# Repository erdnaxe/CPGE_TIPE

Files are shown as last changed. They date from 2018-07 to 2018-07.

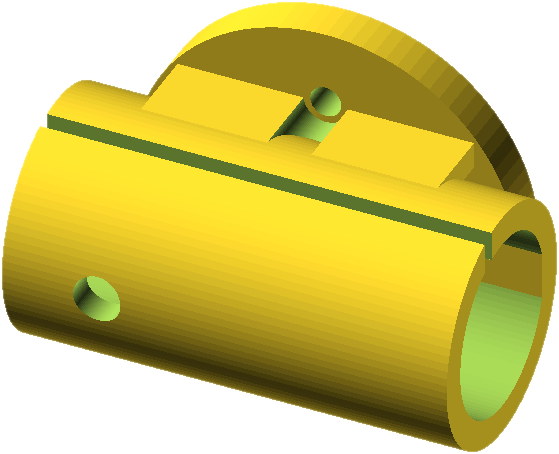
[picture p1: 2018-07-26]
listing_cao/cao/attache-tige_servo.png

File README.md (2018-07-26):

# Mon TIPE de CPGE PSI

Le sujet de mon TIPE est sur la création d'un stabilisateur motorisé à un axe.
Le but est de comprendre et réaliser un système similaire à
[l'OSMO de DJI](https://www.dji.com/fr/osmo).

## Licence

Tout ce TIPE est sous
[licence Creative Commons Attribution-ShareAlike 4.0 International](LICENCE.md).

À noter que SCEI sanctionne sévèrement la copie.

Pour le code, la plus grosse partie est sous
[licence GNU Lesser General Public](https://www.gnu.org/licenses/lgpl-3.0.en.html).

La police de caractère **TeX Gyre Pagella** est sous licence
[GUST Font Source Li­cense (GFSL)](https://ctan.org/license/gfsl).

Si vous avez des questions vous pouvez ouvrir un rapport de bug sur ce projet.

## Contenu

Vous trouverez dans les sous-dossiers :

* [Le listing du code](listing_code) et [le listing de la CAO](listing_cao)
  que j'ai apporté le jour de l'oral.

* [Le code pour traiter l'acquisition de l'expérience du pendule](experience_pendule)

* [La librairie pour contrôler le moteur sans-balais du banc d'essais](https://github.com/erdnaxe/Arduino_BrushlessServo)

* [Le code du banc d'essais sur l'ATMEGA328](tipe-banc_essais)

* [Le code qui permet d'effectuer un échelon sur l'ESP8266](tipe-echelon)

* [Le code qui permet la stabilisation sur l'ESP8266](tipe-stabilisateur)

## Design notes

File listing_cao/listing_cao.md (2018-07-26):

---
lang: fr-FR
papersize: a4
geometry: margin=1.8cm
numbersections: yes
title: Stabilisateur électronique -- CAO
author: Alexandre IOOSS
toc: yes
---

\newpage

\lstset{
  language=C++,
  morekeywords={difference, translate, cube, rotate, cylinder, use}
}

# Conception du stabilisateur

## Impression 3D du boitier accueillant l'électronique

\begin{center}
\vspace{20pt}
\includegraphics[width=0.7\textwidth]{cao/boitier.png}
\vspace{20pt}
\end{center}

## Impression 3D de l'attache de la tige au servomoteur

\begin{center}
\vspace{20pt}
\includegraphics[width=0.3\textwidth]{cao/attache-tige_servo.png}
\vspace{20pt}
\end{center}

Code **OpenSCAD** :

\lstinputlisting{cao/attache-tige_servo.scad}

\newpage

# Conception du banc d'essais

\begin{center}
\vspace{20pt}
\includegraphics[width=\textwidth]{cao/banc_vide.pdf}
\end{center}

\newpage

## Découpe laser des planches pour faire la structure

Échelle 30%. Planche de 6mm *Medium* découpée au laser dans le laboratoire de
fabrication *SqyLab*. Le tout est monté sur une planche de largeur 202mm et de
hauteur 22mm.

\begin{center}
\vspace{20pt}
\includegraphics[scale=0.3]{cao/banc_back.eps}

\includegraphics[scale=0.3]{cao/banc_left.eps}

\includegraphics[scale=0.3]{cao/banc_right.eps}
\end{center}

\newpage

## Impression 3D de l'attache du potentiomètre au banc d'essais

\begin{center}
\vspace{20pt}
\includegraphics[width=0.5\textwidth]{cao/attache_potentiometre.png}
\vspace{20pt}
\end{center}

Code **OpenSCAD** :

\lstinputlisting{cao/attache_potentiometre.scad}

\newpage

## Impression 3D de l'engrenage entre le moteur et le potentiomètre

\begin{center}
\vspace{20pt}
\includegraphics[width=0.3\textwidth]{cao/pignon_moteur.png}
\hspace{10pt}
\includegraphics[width=0.3\textwidth]{cao/pignon_potentiometre.png}
\vspace{20pt}
\end{center}

Code **OpenSCAD** du pignon du moteur :

\lstinputlisting{cao/pignon_moteur.scad}

Code **OpenSCAD** du pignon du potentiomètre :

\lstinputlisting{cao/pignon_potentiometre.scad}

\newpage

# Modèle pour trouver une approximation de l'inertie de l'appareil photo

Masse : 228 grammes

\begin{center}
\vspace{20pt}
\includegraphics[width=0.8\textwidth]{cao/modele_app_photo.pdf}
\vspace{20pt}
\end{center}

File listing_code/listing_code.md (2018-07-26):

---
lang: fr-FR
papersize: a4
geometry: margin=1.8cm
numbersections: yes
title: Stabilisateur électronique -- Listing
author: Alexandre IOOSS
toc: yes
---

\newpage

# Code utilisant le Framework Arduino (pour ATMEGA328p et ESP8266)

\lstset{
  language=C++,
  morekeywords={SimpleTimer, Servo, WebSocketsServer, IPAddress, WiFi, uint32_t, uint8_t, WStype_t, size_t, String}
}

## Bibliothèque pour asservir en position un moteur Brushless

Bibliothèque `BrushlessServo` maintenant publiée dans les contributions de l'éditeur Arduino.

### BrushlessServo.h

\lstinputlisting{brushlessservo/BrushlessServo.h}

### BrushlessServo.cpp

\lstinputlisting{brushlessservo/BrushlessServo.cpp}

### SinArray.h

\lstinputlisting{brushlessservo/SinArray.h}

### SinArray.cpp

\lstinputlisting{brushlessservo/SinArray.cpp}

\newpage

## Bibliothèque pour utiliser l'algorithme constructeur de la centrale inertielle

Programme basé sur l'example du projet *The I2C Device Library*.

### centrale_inertielle.h

\lstinputlisting{../tipe-banc_essais/src/centrale_inertielle.h}

### centrale_inertielle.cpp

\lstinputlisting{../tipe-banc_essais/src/centrale_inertielle.cpp}

\newpage

## Programme pour envoyer des commandes en rampe au servomoteur (ESP8266)

### main.cpp

\lstinputlisting{../tipe-echelon/src/main.cpp}

\newpage

## Programme embarqué sur le stabilisateur finalisé (ESP8266)

### main.cpp

\lstinputlisting{../tipe-stabilisateur/src/main.cpp}

\newpage

## Programme embarqué sur le banc d'essais (ATMega328p)

### main.cpp

\lstinputlisting{../tipe-banc_essais/src/main.cpp}

\newpage

## Bibliothèques externes

### WebSockets (Arduino Framework)

Utilisée sur le stabilisateur pour héberger un serveur au standard WebSocket.

Sous licence GNU LGPL 2.1+.

### SimpleTimer (Arduino Framework)

Utilisée sur le stabilisateur pour obtenir un semblant de multitâche.

Sous licence GNU LGPL 2.1+.

### PID (Brett Beauregard, Arduino Framework)

Utilisée sur le stabilisateur pour l'asservissement.

Développée par *Brett Beauregard* sous licence MIT.

### I2Cdevlib-MPU6050 (The I2C Device Library)

Utilisée pour envoyer l'algorithme constructeur (de MotionApps) sur le Digital
Motion Unit de la centrale inertielle.

Dérivée par le projet *The I2C Device Library* de la librarie de *MotionApps*
sous licence MIT.

\cleardoublepage

# Code Python

\lstset{
  language=Python,
  morekeywords={}
}

## Script pour tester le stabilisateur et configurer les coefficients du correcteur à la volée

### test_stabilisateur.py

\lstinputlisting{../tipe-stabilisateur/python/test_stabilisateur.py}

## Script pour commander le banc d'essais

### ComBanc.py : définit un objet représentant le banc d'essais

\lstinputlisting{../tipe-banc_essais/python/ComBanc.py}

\newpage

### Bode.py : définit un objet représentant un diagramme de Bode

\lstinputlisting{../tipe-banc_essais/python/Bode.py}

\newpage

### BodeTF.py : extension de l'objet Bode pour tracer une fonction de transfert

\lstinputlisting{../tipe-banc_essais/python/BodeTF.py}

\newpage

### test_banc.py : exemple de code pour une commande du banc

\lstinputlisting{../tipe-banc_essais/python/test_banc.py}

\newpage

### bode_centrale_inertielle.py : Création du Bode expérimental de la centrale inertielle

\lstinputlisting{../tipe-banc_essais/python/bode_centrale_inertielle.py}

\newpage

## Script pour le traitement du signal du pendule pesant

### pendule.py

\lstinputlisting{../experience_pendule/pendule.py}

\cleardoublepage

# Code MATLAB pour acquérir les rampes envoyées au servomoteur

\lstset{
  language=MatLab,
  morekeywords={classdef, methods, properties}
}

## Fonctions

### reel_faireAcquisition.m : acquisition d'une rampe sur le servomoteur

\lstinputlisting{../matlab/reel_faireAcquisition.m}

### reel_faireRegression.m : régression affine entre l'entrée et la sortie

\lstinputlisting{../matlab/reel_faireRegression.m}

### reel_rognerRampe.m : rogne le signal de 5s au début et à la fin

\lstinputlisting{../matlab/reel_rognerRampe.m}

### reel_traceCourbe.m : trace l'entrée et la sortie du servomoteur

\lstinputlisting{../matlab/reel_traceCourbe.m}

### reel_traceRegression.m : trace la sortie en fonction de l'entrée du servomoteur (avec superposition de la régression)

\lstinputlisting{../matlab/reel_traceRegression.m}

### reel_SystemeReel.m : définit un objet représentant la communication avec le système réel

\lstinputlisting{../matlab/reel_SystemeReel.m}

\newpage

## Scripts d'exemple

### Effectue un grand nombre d'essais pour affiner la régression

\lstinputlisting{../matlab/reel_SCRIPT5_regressions.m}

### Test de suivi d'une rampe

\lstinputlisting{../matlab/reel_SCRIPT6_suivi.m}

\newpage

# Simulations MATLAB Simulink

## Simulation du servomoteur

\begin{center}
\includegraphics[height=23cm]{assets/modele_rampe.pdf}
\end{center}

## Simulation complète du stabilisateur

\begin{center}
\includegraphics[height=23cm]{assets/modele_stabilisateur.pdf}
\end{center}

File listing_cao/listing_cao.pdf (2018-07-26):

# Stabilisateur électronique – CAO

### Alexandre IOOSS

## Table des matières

1 Conception du stabilisateur | 2
2 Conception du banc d’essais | 4
3 Modèle pour trouver une approximation de l’inertie de l’appareil photo | 8

1

## 1 Conception du stabilisateur

### 1.1 Impression 3D du boitier accueillant l’électronique

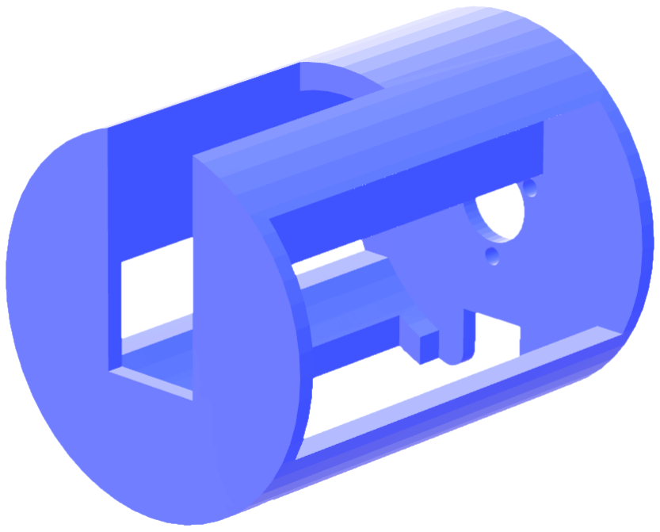
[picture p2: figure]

### 1.2 Impression 3D de l’attache de la tige au servomoteur

Code OpenSCAD :

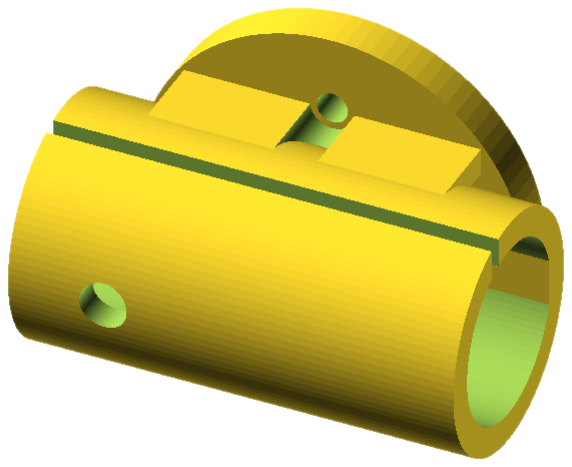
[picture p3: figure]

1 | $fn=100; | // Nombre de facettes dans une révolution
2 | gap = 0.05; | // Espace pour encastrer les pièces

3
4 | /* Tige */
5 | module tige() {
6 | longueur_tige = 330.8; | // Mesurée au pied à coulisse
7 | diametre_tige = 12 + gap; | // ISO + espace pour emboîter
8 | decalage_trou = 8.6; | // Mesuré au pied à coulisse

9
10 | color([0.5, 0.5, 0.5, 1]) rotate([0,90,0]) difference() {
11 | cylinder(h=longueur_tige , r=diametre_tige/2, center=true); | // Tige
12 | translate([0,6.8,0]) cube([20,2,30], center=true); | // Partie limée
2 | Alexandre IOOSS

13 | translate([0,0,-decalage_trou]) rotate([90,0,0])
14 | cylinder(h=20, r=1.5+gap, center=true); | // Perçage
15 | }
16 | }

17
18 | /* Attache servo -tige */
19 | module attache_servo_tige() {
20 | distance_attache = 16; | // Distance entre les 2 trous sur l'attache servo
21 | epaisseur_attache = 3; | // Épaisseur de l'attache donnée par le constructeur
22 | diametre_tige = 12 + gap; | // ISO + espace pour emboîter
23 | decalage_trou = 8.6; | // Mesuré au pied à coulisse

24
25 | union() {
26 | // Partie épousant la forme de la tige
27 | difference() {
28 | rotate([0, 90, 0]) cylinder(h=30, r=8, center=true);
29 | tige();
30 | translate([-decalage_trou ,0,0])
31 | rotate([90,0,0]) cylinder(h=20, r=1.5+gap*2, center=true);

32
33 | // Ajout suite au prototype : permet d'autoriser une déformation
34 | translate([0,-2,7]) cube([32,1,5], center=true);
35 | }

36
37 | // Partie d'accroche au moteur
38 | difference() {
39 | translate([0,8.2,0]) rotate([90,0,0])
40 | cylinder(r=13, h=epaisseur_attache , center=true); | // Forme de base
41 | translate([-decalage_trou ,8,0]) rotate([90,0,0])
42 | cylinder(h=5, r=5.3/2+gap, center=true); | // Trou de la vis
43 | translate([0,8,distance_attache/2]) rotate([90,0,0])
44 | cylinder(h=5, r=1+gap, center=true); | // Trou en haut
45 | translate([0,8,-distance_attache/2]) rotate([90,0,0])
46 | cylinder(h=5, r=1+gap, center=true); | // Trou en bas
47 | }

48
49 | // Renforcements
50 | difference() {
51 | translate([-10,0,diametre_tige/2+gap]) cube([20,8,1.8]);
52 | translate([0,5,distance_attache/2]) rotate([90,0,0]) cylinder(h=10, r=1.5,
center=true);
53 | }
54 | difference() {
55 | translate([-10,0,-1.9-diametre_tige/2-gap]) cube([20,8,1.8]);
56 | translate([0,5,-distance_attache/2]) rotate([90,0,0]) cylinder(h=10, r=1.5,
center=true);
57 | }
58 | }
59 | }

60
61 attache_servo_tige();

## 2 Conception du banc d’essais

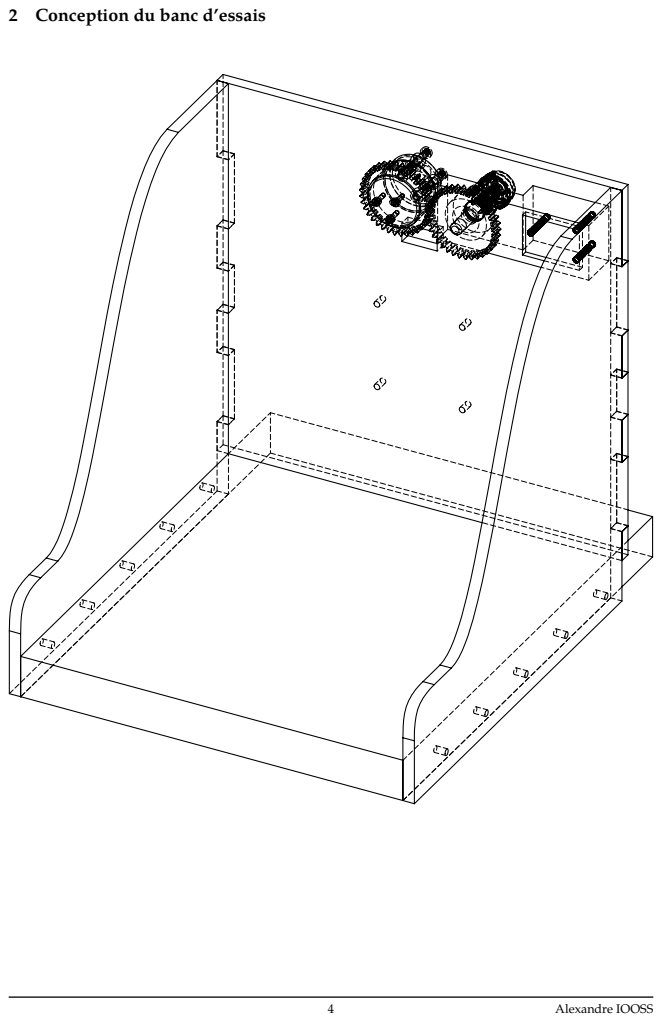
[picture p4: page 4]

### 2.1 Découpe laser des planches pour faire la structure

Échelle 30%. Planche de 6mm Medium découpée au laser dans le laboratoire de fabrication SqyLab. Le tout est monté sur une planche de largeur 202mm et de hauteur 22mm.

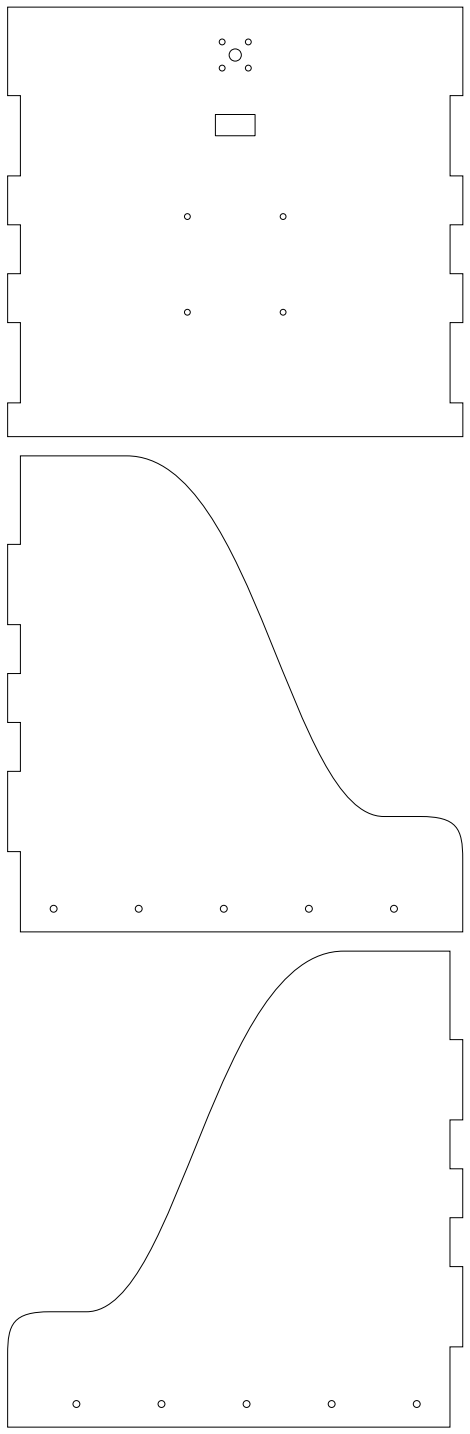
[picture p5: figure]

### 2.2 Impression 3D de l’attache du potentiomètre au banc d’essais

Code OpenSCAD :

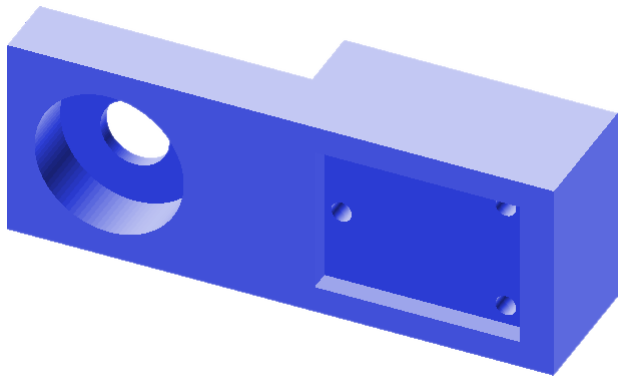
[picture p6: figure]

1 | $fn = 100; | // Nombre de facettes dans une révolution
2 | d | = 21.8; // Diamètre du roulement
3 | l | = 65; | // Distance centre axe - bord droit
4 | h | = 20; | // Profondeur de la piece

5
6 | hauteur = d+4*2; | // Hauteur de la pièce
7 | vide = 22.4-6.5; | // Vide derrière le roulement

8
9 | difference() {
10 | translate([-l/2-d/2-4,-h/2,-hauteur/2]) | cube([l+d/2+4, h, hauteur]);

11
12 | // Trous pour le potentiomètre et son roulement
13 | translate([-l/2,-h/2+8,0]) rotate([90,0,0]) cylinder(r=d/2,h=8+1);
14 | translate([-l/2,-h/2+30,0]) rotate([90,0,0]) cylinder(r=5,h=60);

15
16 | // Vide derrière
17 | translate([-l/2-d/2-4-40,0,-hauteur/2-1]) cube([l+d/2+4, h/2+1, hauteur+2]);
18 | translate([l/2+5-40,-h/2-1,-(hauteur -8)/2]) cube([40-10,h-vide,hauteur -8]);

19
20 | // Trous pour les 3 vis
21 | translate([0,-h/2+30,0]) rotate([90,0,0]) cylinder(r=3/2,h=60);
22 | translate([24,-h/2+30,+8]) rotate([90,0,0]) cylinder(r=3/2,h=60);
23 | translate([24,-h/2+30,-8]) rotate([90,0,0]) cylinder(r=3/2,h=60);
24 | }

### 2.3 Impression 3D de l’engrenage entre le moteur et le potentiomètre

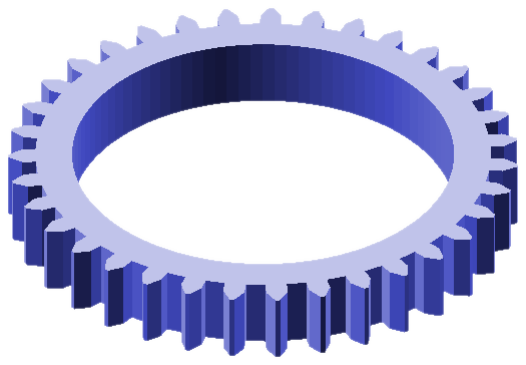
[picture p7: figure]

Code OpenSCAD du pignon du moteur :

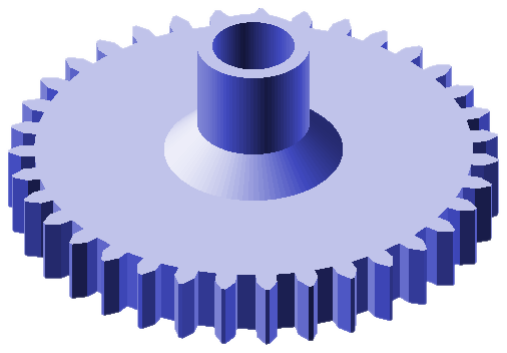
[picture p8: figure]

1 // Bibliothèque Gear Generator écrite par Longrange , sous licence Creative Commons Attribution.
2 use <GearGeneratorV2.scad >;

3
4 | r = 27.7/2; | // Rayon du moteur

5
6 | difference() {
7 | linear_extrude(height=5, center=true , convexity=10)
8 | | gear(number_of_teeth=35,diametral_pitch=1);
9 | cylinder(h=5*4, r=r, center=true , $fn=100);
10 | }

Code OpenSCAD du pignon du potentiomètre :

1 // Bibliothèque Gear Generator écrite par Longrange , sous licence Creative Commons Attribution.
2 use <GearGeneratorV2.scad >;

3
4 | r = 6/2+0.1; | // Rayon de l'axe du potentiomètre

5
6 | difference() {
7 | union() {
8 | linear_extrude(height=5, center=true , convexity=10)
9 | | gear(number_of_teeth=35,diametral_pitch=1);
10 | cylinder(h=5, r1=8/2+0.25+5, r2=8/2+0.25, $fn=100);
11 | cylinder(h=5+7, r=8/2+0.25, $fn=100);
12 | }
13 | cylinder(h=(5+10)*2, r=r, center=true , $fn=100);
14 | }

## 3 Modèle pour trouver une approximation de l’inertie de l’appareil photo

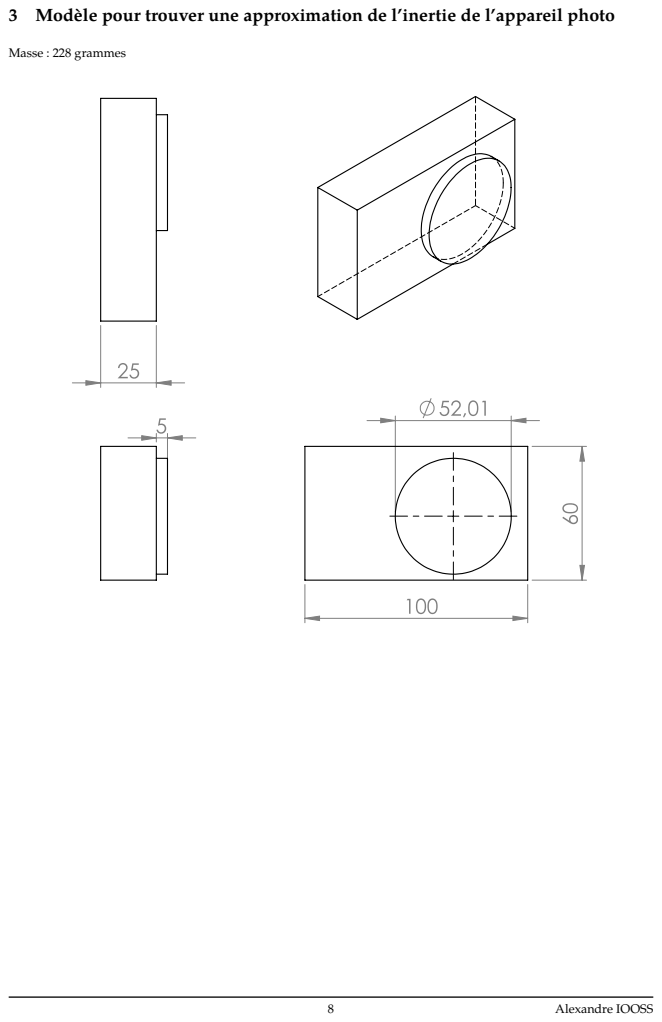
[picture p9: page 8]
Masse : 228 grammes

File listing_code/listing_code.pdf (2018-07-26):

# Stabilisateur électronique – Listing

### Alexandre IOOSS

## Table des matières

1 Code utilisant le Framework Arduino (pour ATMEGA328p et ESP8266) | 2
2 Code Python | 13
3 Code MATLAB pour acquérir les rampes envoyées au servomoteur | 21

3.1.5 reel_traceRegression.m : trace la sortie en fonction de l’entrée du servomoteur (avec

3.1.6 reel_SystemeReel.m : définit un objet représentant la communication avec le système réel . . . . | 22
4 Simulations MATLAB Simulink | 25

1

## 1 Code utilisant le Framework Arduino (pour ATMEGA328p et ESP8266)

### 1.1 Bibliothèque pour asservir en position un moteur Brushless

Bibliothèque BrushlessServo maintenant publiée dans les contributions de l’éditeur Arduino.

### 1.1.1 BrushlessServo.h

1 | #ifndef BRUSHLESS_SERVO_H
2 | #define BRUSHLESS_SERVO_H

3
4 | #include "Arduino.h"
5 | #include "SinArray.h"

6
7 | #ifndef PWMRANGE // PWMRANGE is already defined on some microcontroller
8 | #define PWMRANGE 255 // Default for ATMEGA328 (Arduino UNO)
9 | #endif

10
11 | class BrushlessServo {
12 | public:
13 | void attach(int p1, int p2, int p3); // Initialization
14 | void write(float angle); | // Move to a angle in degree
15 | void setOutputPower(int power_mult); // Set a power multiplier from 0 to PWMRANGE
16 | void setCycles(int n); | // Set how many sinusoide periods are
17 | | // needed for one revolution
18 | private:
19 | SinArray sinArray;
20 | int pins[3];
21 | int power = PWMRANGE;
22 | int n_cycles = 8;
23 | };

24
25 | #endif
| 1.1.2 BrushlessServo.cpp
1 | #include "BrushlessServo.h"

2
3 | void BrushlessServo::attach(int p1, int p2, int p3) {
4 | // Set output pins
5 | pins[0] = p1;
6 | pins[1] = p2;
7 | pins[2] = p3;
8 | pinMode(p1, OUTPUT);
9 | pinMode(p2, OUTPUT);
10 | pinMode(p3, OUTPUT);

11
12 | // Generate sin table for faster control
13 | sinArray.generate();
14 | }

15
16 | void BrushlessServo::write(float angle) {
17 | float real_angle = n_cycles * angle;

18
19 | int pwm1 = (float)power * (sinArray.getSinDegree(real_angle) + 1.) / 2.;
20 | int pwm2 = (float)power * (sinArray.getSinDegree(real_angle + 120) + 1.) / 2.;
21 | int pwm3 = (float)power * (sinArray.getSinDegree(real_angle + 240) + 1.) / 2.;

22
23 | // Set PWMs
24 | analogWrite(pins[0], pwm1);
25 | analogWrite(pins[1], pwm2);
26 | analogWrite(pins[2], pwm3);
27 | }

28
29 | void BrushlessServo::setOutputPower(int power_mult) { power = power_mult; }
2 | Alexandre IOOSS

30
31 void BrushlessServo::setCycles(int n) { n_cycles = n; }

### 1.1.3 SinArray.h

1 // This objet stores sin values in memory for faster calculations.

2
3 | #ifndef SIN_ARRAY_H
4 | #define SIN_ARRAY_H

5
6 #include "Arduino.h"

7
8 | #define N_VALUES 512 // divisions of one period optimized for an Arduino UNO
9 | #define STORE_TYPE int16_t
10 | #define STORE_TYPE_RANGE 32767

11
12 | class SinArray {
13 | public:
14 | void generate(); | // Initialization
15 | double getSinDegree(double a); // Get sin with a in degree
16 | double getSin(double r); | // Get sin with r in radian

17
18 | private:
19 | double getSinByOffset(int offset); // Move to a offset between 0 and PRECISION
20 | static int sin_array[N_VALUES];
21 | static bool sin_array_empty;
22 | };

23
24 | #endif
| 1.1.4 SinArray.cpp
1 | #include "Arduino.h"
2 | #include "SinArray.h"

3
4 | int SinArray::sin_array[N_VALUES];
5 | bool SinArray::sin_array_empty = true;

6
7 | void SinArray::generate() {
8 | // Skip if already done
9 | if (!sin_array_empty) { return; }

10
11 | // Generate sin array
12 | for (int i = 0; i < N_VALUES; i++) {
13 | sin_array[i] = sin(2. * M_PI * i / (double)N_VALUES) * STORE_TYPE_RANGE;
14 | }

15
16 | sin_array_empty = false; | // Mark done
17 | }

18
19 | double SinArray::getSinByOffset(int offset) {
20 | // Offset must be positive and between 0 and N_VALUES -1
21 | offset = offset % N_VALUES;
22 | if (offset < 0) { offset = N_VALUES + offset; }

23
24 | return sin_array[offset] / (double)STORE_TYPE_RANGE;
25 | }

26
27 | double SinArray::getSinDegree(double a) {
28 | int offset = (a * N_VALUES) / 360;
29 | return getSinByOffset(offset);
30 | }

31
32 | double SinArray::getSin(double r) {
33 | int offset = (r * N_VALUES) / (2. * M_PI);
34 | return getSinByOffset(offset);
35 | }

### 1.2 Bibliothèque pour utiliser l’algorithme constructeur de la centrale inertielle

Programme basé sur l’example du projet The I2C Device Library.

### 1.2.1 centrale_inertielle.h

1 | #ifndef IMU_DMP_h
2 | #define IMU_DMP_h

3
4 | #define PIN_SDA A4
5 | #define PIN_SCL A5
6 | #define PIN_INTERRUPTION 2

7
8 | // Paramètres de calibration
9 | #define X_GYRO_OFFSET 99
10 | #define Y_GYRO_OFFSET -1
11 | #define Z_GYRO_OFFSET -4
12 | #define X_ACCEL_OFFSET -2073
13 | #define Y_ACCEL_OFFSET -1429
14 | #define Z_ACCEL_OFFSET 1147

15
16 | extern bool centrale_inertielle_initialisee; // vraie si succès d'initialisation
17 | extern float centrale_inertielle_angles[3]; | // lacet , roulis et tangage (rad)

18
19 | extern void initialiser_centrale_inertielle();
20 | extern void boucle_centrale_inertielle();

21
22 #endif

### 1.2.2 centrale_inertielle.cpp

1 | #include "centrale_inertielle.h"
2 | #include "Arduino.h"
3 | #include "MPU6050_6Axis_MotionApps20.h"

4
5 | // Variables définies dans l'en-tête
6 | bool centrale_inertielle_initialisee = false;
7 | float centrale_inertielle_angles[3];

8
9 | // Variables globales
10 | uint16_t taille_mesure; | // Taille d'une mesure
11 | uint16_t taille_fifo; | // Taille de la file d'attente FIFO
12 | volatile bool interruption = false; // Interruption envoyée par la centrale
13 | MPU6050 centrale_inertielle;

14
15 | // Fonction d'interruption
16 | void interruptionVraie() { interruption = true; }

17
18 | // Initialise la centrale inertielle avec l'algorithme de MotionApps
19 | void initialiser_centrale_inertielle() {
20 | #if defined(__AVR_ATmega328P__)
21 | Wire.begin(); // I2C ATMEGA
22 | #else
23 | Wire.begin(PIN_SDA , PIN_SCL); // I2C ESP8266
24 | #endif
25 | Wire.setClock(400000);

26
27 pinMode(PIN_INTERRUPTION , INPUT); // Entrée de l'interruption

28
29 | centrale_inertielle.initialize(); // Initialisation de la centrale
30 | uint8_t etat = centrale_inertielle.dmpInitialize(); // Initialisation DMP

31
32 | // Calibration
33 | centrale_inertielle.setXGyroOffset(X_GYRO_OFFSET);
34 | centrale_inertielle.setYGyroOffset(Y_GYRO_OFFSET);
35 | centrale_inertielle.setZGyroOffset(Z_GYRO_OFFSET);

centrale_inertielle.setXAccelOffset(X_ACCEL_OFFSET); centrale_inertielle.setYAccelOffset(Y_ACCEL_OFFSET); centrale_inertielle.setZAccelOffset(Z_ACCEL_OFFSET);

if (etat == 0) {
// La centrale marche
centrale_inertielle.setDMPEnabled(true); // Active le module de calcul attachInterrupt(digitalPinToInterrupt(PIN_INTERRUPTION), interruptionVraie , RISING); // Interruption envoyée par la centrale

// Récupération de la taille d'une mesure
taille_mesure = centrale_inertielle.dmpGetFIFOPacketSize();

centrale_inertielle_initialisee = true;

}

}

// Récupère des nouvelles mesures si elles sont disponibles void boucle_centrale_inertielle() {
if ((!interruption && taille_fifo < taille_mesure) || !centrale_inertielle_initialisee) {
return; // Pas encore prête

}

interruption = false;

// Etat actuel de la centrale
uint8_t etat_interruption = centrale_inertielle.getIntStatus();

// Récupère la taille de la liste d'attente
taille_fifo = centrale_inertielle.getFIFOCount();

if ((etat_interruption & 0x10) || taille_fifo == 1024) { // Dépassement de capacité, on réinitialise centrale_inertielle.resetFIFO();
} else if (etat_interruption & 0x02) {
// Attente d'avoir toutes les données (très rapide) while (taille_fifo < taille_mesure) {
taille_fifo = centrale_inertielle.getFIFOCount();

}

// Lecture de la liste FIFO
uint8_t fifoBuffer[64];
centrale_inertielle.getFIFOBytes(fifoBuffer , taille_mesure);

// Nouvelle taille de la liste d'attente
taille_fifo -= taille_mesure;

// Calcul de l'angle en passant par les quaternions
85 | Quaternion q; | // Représente l'orientation
VectorFloat p; // Vecteur pesanteur centrale_inertielle.dmpGetQuaternion(&q, fifoBuffer); centrale_inertielle.dmpGetGravity(&p, &q); centrale_inertielle.dmpGetYawPitchRoll(centrale_inertielle_angles , &q, &p);

}

}

### 1.3 Programme pour envoyer des commandes en rampe au servomoteur (ESP8266)

### 1.3.1 main.cpp

1 | #include "Arduino.h"
2 | #include "ESP8266WiFi.h"
3 | #include <Hash.h>
4 | #include <Servo.h>
5 | #include <SimpleTimer.h>
6 | #include <WebSocketsServer.h>

7
8 | // Timers
9 | SimpleTimer timer_calcul_commande;
10 | SimpleTimer timer_transmission_websocket;

11
12 | // Objets
13 | Servo servomoteur;
14 | WebSocketsServer webSocket = WebSocketsServer (81);

15
16 | // Variables pour la commande
17 | unsigned long temps_commande = 0; // ms, temps à partir du début de la commande
18 | unsigned long temps_commande_orig = 0; // ms, décalage temporel de l'origine
19 | unsigned long temps_duree_rampe = 0; | // ms, durée de la rampe
20 | int angle_servo = 950; | // us, angle à envoyer au servomoteur
21 | const int angle_servo_min = 950; | // us, angle minimal du servomoteur
22 | const int angle_servo_max = 1800; | // us, angle maximal du servomoteur

23
24 | // Initialisation du point d'accès Wifi
25 | void initialiser_wifi() {
26 | WiFi.mode(WIFI_AP); | // Point d'accès WiFi
27 | IPAddress ip_stab(192, 168, 4, 1); | // IP du stabilisateur & passerelle
28 | IPAddress masque(255, 255, 255, 0); // Masque de sous -réseau
29 | WiFi.softAPConfig(ip_stab , ip_stab , masque); // Serveur DHCP
30 | WiFi.softAP("Stabilisateur", "t1p3stabi"); | // Nom et mot de passe du Wifi
31 | }

32
33 | // Commande en rampe
34 | void commande_servomoteur() {
35 | if (temps_duree_rampe == 0) {
36 | // Aucune donnée n'a été reçue donc retour à l'origine
37 | angle_servo = angle_servo_min;
38 | } else {
39 | temps_commande = millis() - temps_commande_orig;

40
41 | if (temps_commande > 5000 and temps_commande < temps_duree_rampe + 5000) {
42 | // Effectue la rampe
43 | angle_servo = (temps_commande - 5000) *
44 | (angle_servo_max - angle_servo_min) /
45 | temps_duree_rampe +
46 | angle_servo_min;
47 | } else if (temps_commande > temps_duree_rampe + 10000) {
48 | // La rampe est terminéee
49 | temps_duree_rampe = 0;
50 | }
51 | }

52
53 | servomoteur.writeMicroseconds(angle_servo);
54 | }

55
56 | // Transmet une mesure vers le socket réseau
57 | void transmission_websocket() {
58 | int pot = analogRead(A0);
59 | String texte =
60 | String(temps_commande) + "," + String(angle_servo) + "," + String(pot);
61 | webSocket.broadcastTXT(texte);
62 | }

63

64 | // Gère la réception d'une commande (inspiré d'un exemple de WebSocket)
65 | void rx_websocket(uint8_t num, WStype_t type, uint8_t *payload , size_t length) {
66 | if (type == WStype_TEXT and payload[0] == '#') {
67 | // Parsing de la commande (de la forme #FFF)
68 | uint32_t recu = (uint32_t)strtol((const char *)&payload[1], NULL, 16);
69 | int num_vitesse = ((recu >> 4) & 0xFF); | // 2 premiers chiffres
70 | int exp_vitesse = ((recu >> 0) & 0xF) - 0x8; // Puissance de 10

71
72 | // Calcul de la vitesse et de la durée de la rampe
73 | float vitesse = num_vitesse * pow(10, exp_vitesse); | // us/ms
74 | temps_duree_rampe = (angle_servo_max - angle_servo_min) / vitesse; // ms

75
76 | // Déplacement de l'origine temporel
77 | temps_commande_orig = millis();

78
79 | // Renvoie de la durée pour vérification
80 | webSocket.broadcastTXT("#" + String(temps_duree_rampe));
81 | }
82 | }

83
84 | // Initialisation
85 | void setup() {
86 | servomoteur.attach(D6); | // Commande du servomoteur
87 | pinMode(A0, INPUT); | // Entrée du potentiomètre du servomoteur
88 | initialiser_wifi(); | // Point d'accès Wifi
89 | webSocket.begin(); | // Initialisation du Websocket
90 | webSocket.onEvent(rx_websocket); // Réception d'une commande

91
92 | timer_calcul_commande.setInterval(25, commande_servomoteur);
93 | timer_transmission_websocket.setInterval(75, transmission_websocket);
94 | }

95
96 | // Boucle principale qui lance les sous -boucles
97 | void loop() {
98 | timer_calcul_commande.run();
99 | timer_transmission_websocket.run();
100 | webSocket.loop();
101 | }

### 1.4 Programme embarqué sur le stabilisateur finalisé (ESP8266)

### 1.4.1 main.cpp

1 | #include "Arduino.h"
2 | #include "ESP8266WiFi.h"
3 | #include "centrale_inertielle.h"
4 | #include <Hash.h>
5 | #include <PID_v1.h>
6 | #include <Servo.h>
7 | #include <SimpleTimer.h>
8 | #include <WebSocketsServer.h>

9
10 | // Variables pour la commande
11 | double angle_mesure = 0.; // rad, angle mesuré par la centrale inertielle
12 | double angle_servo = 0.; | // us, angle à envoyer au servomoteur
13 | double angle_voulu = 0.; | // Angle correspondant à l'horizontale

14
15 | // Objets
16 | SimpleTimer timer_transmission_websocket;
17 | Servo servomoteur;
18 | WebSocketsServer webSocket = WebSocketsServer (81);
19 | PID correcteur(&angle_mesure , &angle_servo , &angle_voulu , 100, 3300, 0,
20 | REVERSE); // Kp=100, Ki=Kd=0

21
22 | // Initialisation du point d'accès Wifi
23 | void initialiser_wifi() {
24 | WiFi.mode(WIFI_AP); | // Point d'accès WiFi
25 | IPAddress ip_stab(192, 168, 4, 1); | // IP du stabilisateur & passerelle
26 | IPAddress masque(255, 255, 255, 0); // Masque de sous -réseau
27 | WiFi.softAPConfig(ip_stab , ip_stab , masque); // Serveur DHCP
28 | WiFi.softAP("Stabilisateur", "t1p3stabi"); | // Nom et mot de passe du Wifi
29 | }

30
31 | // Transmet une mesure vers le socket réseau
32 | void transmission_websocket() {
33 | int pot = analogRead(A0);
34 | int temps_actuel = millis();
35 | String texte = String(temps_actuel) + "," + String(angle_servo) + "," +
36 | String(pot) + "," + String(angle_mesure);
37 | webSocket.broadcastTXT(texte);
38 | }

39
40 | // Gère la réception d'une commande
41 | void rx_websocket(uint8_t num, WStype_t type, uint8_t *payload , size_t length) {
42 | if (type == WStype_BIN) {
43 | double *donnees = (double *)payload; // On reçoit 3 double

44
45 | if (length / sizeof(double) != 3) {
46 | // Si on ne reçoit pas 3 éléments , alors problème
47 | return;
48 | }

49
50 | // On change les paramètres du correcteur
51 | correcteur.SetTunings(donnees[0], donnees[1], donnees[2]);
52 | }
53 | }

54
55 | // Initialisation
56 | void setup() {
57 | servomoteur.attach(D6); | // Commande du servomoteur
58 | pinMode(A0, INPUT); | // Entrée du potentiomètre du servomoteur
59 | initialiser_centrale_inertielle(); // Centrale inertielle
60 | initialiser_wifi(); | // Point d'accès Wifi
61 | webSocket.begin(); | // Initialisation du Websocket
62 | webSocket.onEvent(rx_websocket); | // Réception d'une commande

63

64 | // Transmet une valeur toutes les 60ms
65 | timer_transmission_websocket.setInterval(60, transmission_websocket);

66
67 | correcteur.SetOutputLimits(-825, 825); // Domaine délimité en us
68 | correcteur.SetSampleTime(20); | // Calcul tous les 25ms
69 | correcteur.SetMode(AUTOMATIC); | // Active le correcteur
70 | }

71
72 | // Boucle principale qui lance les sous -boucles
73 | void loop() {
74 | // Appel des différents Timer
75 | boucle_centrale_inertielle(); | // Centrale inertielle
76 | correcteur.Compute(); | // Correcteur
77 | timer_transmission_websocket.run(); // Transmission des données
78 | webSocket.loop(); | // WebSocket

79
80 | // Transfert des variables
81 | angle_mesure = centrale_inertielle_angles[2];
82 | servomoteur.writeMicroseconds(angle_servo+1375);
83 | }

### 1.5 Programme embarqué sur le banc d’essais (ATMega328p)

### 1.5.1 main.cpp

1 | #include "Arduino.h"
2 | #include "BrushlessServo.h"
3 | #include "SinArray.h"
4 | #include "centrale_inertielle.h"

5
6 | // Objets
7 | BrushlessServo moteur;
8 | SinArray sinArray;

9
10 | // Variables pour la commande
11 | int amplitude = 10; // en degrés
12 | float pulsation = 0.;
13 | float angle_moteur = 0.; | // en degrés
14 | unsigned long temps_debut = 0; // origine temporelle

15
16 | unsigned long temps_precedent_commande_moteur_boucle = 0;
17 | unsigned long temps_precedent_transmission_serie_boucle = 0;
18 | unsigned long temps_actuel = 0; // en ms

19
20 | // Commande du moteur
21 | void commande_moteur() {
22 | // Toutes les 10ms
23 | if (temps_actuel - temps_precedent_commande_moteur_boucle >= 10) {
24 | temps_precedent_commande_moteur_boucle = temps_actuel;

25
26 | // Commande du moteur
27 | if (pulsation > 0.1) {
28 | angle_moteur =
29 | amplitude * sinArray.getSin(pulsation * temps_actuel / 1000.);
30 | moteur.write(-angle_moteur - 20);
31 | }
32 | }
33 | }

34
35 | // Gère la réception d'une commande
36 | void reception_serie() {
37 | if (Serial.available() > 0) { | // Si on a reçu quelque chose
38 | pulsation = Serial.parseFloat(); // Reception d'une nouvelle pulsation

39
40 | // Nouvelle origine des temps
41 | temps_debut = millis();
42 | temps_precedent_commande_moteur_boucle = 0;
43 | temps_precedent_transmission_serie_boucle = 0;
44 | }
45 | }

46
47 | // Transmet une mesure sur le port série
48 | void transmission_serie() {
49 | // Toutes les 10 ms
50 | if (temps_actuel - temps_precedent_transmission_serie_boucle >= 10) {
51 | temps_precedent_transmission_serie_boucle = temps_actuel;

52
53 | Serial.print(millis() - temps_debut);
54 | Serial.print(",");
55 | Serial.print(String(angle_moteur , 4));
56 | Serial.print(",");
57 | Serial.print(analogRead(A0));
58 | Serial.print(",");
59 | Serial.print(String(centrale_inertielle_angles[0], 4));
60 | Serial.print(",");
61 | Serial.print(String(centrale_inertielle_angles[1], 4));
62 | Serial.print(",");
63 | Serial.println(String(centrale_inertielle_angles[2], 4));

64 | }
65 | }

66
67 | // Initialisation
68 | void setup() {
69 | // Fast PWM Mode , diviseur de 1 : 16MHz/256
70 | // Extrait de https://www.arduino.cc/en/Tutorial/SecretsOfArduinoPWM
71 | TCCR1B = (TCCR1B & 0b11111000) | 0x01;
72 | TCCR2B = (TCCR2B & 0b11111000) | 0x01;

73
74 | moteur.attach(9, 10, 11); // Définition du moteur Brushless
75 | // moteur.setOutputPower (160); | // Réduction de la tension

76
77 | Serial.begin(115200); | // Communication série
78 | pinMode(A0, INPUT); | // Entrée du potentiomètre
79 | sinArray.generate(); | // Précalcul du table de valeurs de sinus
80 | initialiser_centrale_inertielle(); // Centrale inertielle
81 | }

82
83 | // Boucle principale du programme
84 | void loop() {
85 | // On arrête le programme si la centrale ne fonctionne pas
86 | if (!centrale_inertielle_initialisee)
87 | return;

88
89 temps_actuel = millis() - temps_debut;

90
91 | boucle_centrale_inertielle(); // Centrale inertielle
92 | commande_moteur(); | // Commande du moteur
93 | transmission_serie(); | // Transmission des mesures
94 | reception_serie(); | // Réception d'une commande
95 | }

### 1.6 Bibliothèques externes

### 1.6.1 WebSockets (Arduino Framework)

Utilisée sur le stabilisateur pour héberger un serveur au standard WebSocket.

Sous licence GNU LGPL 2.1+.

### 1.6.2 SimpleTimer (Arduino Framework)

Utilisée sur le stabilisateur pour obtenir un semblant de multitâche.

Sous licence GNU LGPL 2.1+.

### 1.6.3 PID (Brett Beauregard, Arduino Framework)

Utilisée sur le stabilisateur pour l’asservissement.

Développée par Brett Beauregard sous licence MIT.

### 1.6.4 I2Cdevlib-MPU6050 (The I2C Device Library)

Utilisée pour envoyer l’algorithme constructeur (de MotionApps) sur le Digital Motion Unit de la centrale inertielle.

Dérivée par le projet The I2C Device Library de la librarie de MotionApps sous licence MIT.

## 2 Code Python

2.1 Script pour tester le stabilisateur et configurer les coefficients du correcteur à la volée

### 2.1.1 test_stabilisateur.py

1 | from websocket import create_connection
2 | import matplotlib.pyplot as plt
3 | import numpy as np
4 | from struct import pack

5

6
7 | def faire_acquisition(kp, ki, kd, n_mesures):
8 | """ Règle le correcteur et réalise une acquisition en Wifi """

9
10 ws = create_connection("ws://192.168.4.1:81")

11
12 | # Réglage du correcteur
13 | param_bin = pack('ddd', kp, ki, kd)
14 | ws.send_binary(param_bin)

15
16 | # Réception
17 | donnees = np.zeros((n_mesures , 4), dtype=np.float)
18 | for i in range(n_mesures):
19 | recu = ws.recv()
20 | print(recu)
21 | donnees[i, :] = recu.split(",")

22
23 ws.close()

24
25 | # Conversions
26 | temps = (donnees[:, 0] - donnees[0, 0]) / 1000 | # Temps en seconde
27 | servo = donnees[:, 1] + 1375 | # Commande servomoteur en us
28 | pot = donnees[:, 2] | # Valeur CAN du potentiomètre
29 | imu = donnees[:, 3] * 180 / np.pi | # Angle de la centrale en degrées

30
31 | return temps , servo , pot, imu

32

33
34 | def tracer_entree_sortie_correcteur(temps , servo , pot, imu):
35 | plt.figure(figsize=(12, 4))

36
37 | plt.subplot("121")
38 | plt.plot(temps , imu, label="Centrale inertielle")
39 | plt.title("Signal d'erreur")
40 | plt.xlabel("Temps (secondes)")
41 | plt.ylabel("Angle (degrés)")
42 | plt.legend(); plt.grid(); plt.ylim(-90, 90)

43
44 | plt.subplot("122")
45 | plt.plot(temps , servo , label="Commande servomoteur")
46 | plt.title("Sortie du correcteur")
47 | plt.xlabel("Temps (secondes)")
48 | plt.ylabel("Commande (us)")
49 | plt.legend(); plt.grid(); plt.ylim(550, 2200)

50
51 | plt.tight_layout()
52 | plt.show()

53

54
55 | # Réglages
56 | kp, ki, kd = 100., 3300., 0.
57 | n_mesures = 100

58
59 | temps , servo , pot, imu = faire_acquisition(kp, ki, kd, n_mesures)
60 | tracer_entree_sortie_correcteur(temps , servo , pot, imu)

### 2.2 Script pour commander le banc d’essais

### 2.2.1 ComBanc.py : définit un objet représentant le banc d’essais

import serial
import time
import numpy as np

class ComBanc(serial.Serial):
"""
Représente la communication avec le banc d'essais , hérite de Serial """

def __init__(self, baudrate=9600, port='COM1'):
super().__init__()

self.baudrate = baudrate
self.port = port

def open(self):
# Ouverture de la communication super().open()

# Attendre que le banc démarre

time.sleep(2)

def changer_pulsation(self, omega):
""" Permet de changer la pulsation de la sollicitation harmonique """

print("Nouvelle pulsation :", omega)

# Envoie de la commande

cmd = str(omega)
self.write(cmd.encode('utf -8'))

# Attendre que le banc prenne la valeur en compte time.sleep(2)

def acquisition(self, n):
""" Permet d'acquerir n valeurs séparées par une virgule """

# Vider le buffer d'entree

self.flushInput()

# Information

print("Acquisition de " + str(n) + " couples")

# Acquisition

mesures = []
for i in range(n):
try:
rx = str(self.readline()).split(",") mesures.append([
float(rx[0][2:]),
float(rx[1]),
float(rx[2]),
float(rx[3]),
float(rx[4]),
float(rx[5][:-5])

])
print(mesures[-1])
except ValueError:
print("Erreur de reception")

return np.array(mesures)

### 2.2.2 Bode.py : définit un objet représentant un diagramme de Bode

import numpy as np
import matplotlib.pyplot as plt

class Bode:
"""
Objet représentant un diagramme de Bode
"""

def __init__(self, title="", puissance_dix_min=-1, puissance_dix_max=2): self.title = title
self.puissance_dix_min = puissance_dix_min
self.puissance_dix_max = puissance_dix_max

self.omegas = []
self.gains = []
self.phases = []

def plot_gain(self):
""" Trace le diagramme des gains """

plt.plot(self.omegas , self.gains , color="green")

# Réglages

plt.xscale("log")
plt.xlim(10**self.puissance_dix_min , 10**self.puissance_dix_max) plt.title(self.title)
plt.grid()
plt.xlabel("x")
plt.ylabel("GdB")
plt.axhline(color="black")

def plot_phase(self):
""" Trace le diagramme des phases """

plt.plot(self.omegas , self.phases , color="green")

# Réglages

plt.xscale("log")
plt.xlim(10**self.puissance_dix_min , 10**self.puissance_dix_max) plt.grid()
plt.xlabel("omega")
plt.ylabel("Phase")
plt.axhline(color="black")

def plot(self):
""" Trace le diagramme de Bode complet """

plt.subplot(211)
self.plot_gain()

plt.subplot(212)
self.plot_phase()

### 2.2.3 BodeTF.py : extension de l’objet Bode pour tracer une fonction de transfert

import numpy as np
import matplotlib.pyplot as plt
from Bode import Bode

class BodeTF(Bode):
"""
Objet représentant un diagramme de Bode créé à partie d'une fonction de transfert
"""

def calc_gain(v):
""" Calcule le gain en décibel du complexe v """

return 20 * np.log10(abs(v))

def calc_phase(v):
""" Calcule la phase du complexe v """

r = v.real
i = v.imag

if r == 0:
return 0
elif r * i > 0:
return np.arctan(i / r) - np.pi else:
return np.arctan(i / r)

def plot(self, fonction_de_transfert):
""" Trace le diagramme des gains et des phases d'une fonction de transfert """

# Calcul des points

self.omegas = np.logspace(self.ten_pow_min , self.ten_pow_max , 100)
vals = [fonction_de_transfert(x) for x in self.omegas]
self.gains = [self.calc_gain(v) for v in vals]
self.phases = [self.calc_phase(v) for v in vals]

# Affichage

super().plot()

### 2.2.4 test_banc.py : exemple de code pour une commande du banc

1 | from ComBanc import ComBanc
2 | import matplotlib.pyplot as plt
3 | import numpy as np
4 | import time

5
6 amplitude = 10

7

8
9 | def acquisition(banc, omega):
10 | """
11 | Réalise une sollicitation harmonique et renvoie les mesures du potentiomètre
12 | et de la centrale inertielle en fonction du temps ainsi que la commande
13 | """

14
15 | banc.open() | # Ouvre la connexion et démarre le banc d'essais
16 | time.sleep(5) | # Laisse le temps à la centrale de converger
17 | banc.changer_pulsation(omega)

18
19 | # Acquisition de 1000 valeurs (1000*0.01 = 1s)
20 | mesures = banc.acquisition(1000)

21
22 | # Alignement du potentiomètre et conversions
23 | temps = mesures[:, 0] / 1000 | # en secondes
24 | max_pot = max(mesures[:, 2])
25 | moy_pot = (max_pot + min(mesures[:, 2])) / 2
26 | commande = mesures[:, 1]
27 | potentiometre = (mesures[:, 2] - moy_pot) / (
28 | max_pot - moy_pot) * amplitude | # en degrées
29 | imu = -mesures[:, 5] * 180 / np.pi | # en degrées

30
31 | banc.close() | # Fermeture de la connexion

32
33 | return [temps , commande , potentiometre , imu]

34

35
36 | def tracer_potentiometre_imu(temps , commande , potentiometre , imu):
37 | plt.figure(figsize=(8, 4))

38
39 | plt.subplot(211)
40 | plt.title("Commande et retour potentiomètre")
41 | plt.plot(temps , commande , "+:", label="Commande")
42 | plt.plot(temps , potentiometre , "+:", label="Potentiomètre")
43 | plt.xlabel("Temps (en secondes)")
44 | plt.grid()
45 | plt.legend()

46
47 | plt.subplot(212)
48 | plt.title("Commande et retour MPU6050")
49 | plt.plot(temps , commande , "+:", label="Commande")
50 | plt.plot(temps , imu, "+:", label="MPU6050 (Roulis)")
51 | plt.xlabel("Temps (en secondes)")
52 | plt.grid()
53 | plt.legend()

54
55 | plt.tight_layout()

56

57
58 | # Instance du banc d'essais
59 | banc = ComBanc(baudrate=115200, port='/dev/ttyUSB0')

60
61 | temps , commande , potentiometre , imu = acquisition(banc, 3.14156)
62 | tracer_potentiometre_imu(temps , commande , potentiometre , imu)

63
64 plt.show()

2.2.5 bode_centrale_inertielle.py : Création du Bode expérimental de la centrale inertielle

1 | from Bode import Bode
2 | from ComBanc import ComBanc
3 | import matplotlib.pyplot as plt
4 | import numpy as np
5 | import time

6

7
8 | def acquisition(banc, omega):
9 | """
10 | Réalise une sollicitation harmonique et renvoie les mesures du potentiomètre
11 | et de la centrale inertielle en fonction du temps ainsi que la commande
12 | """

13
14 | banc.open() | # Ouvre la connexion et démarre le banc d'essais
15 | time.sleep(5) | # Laisse le temps à la centrale de converger
16 | banc.changer_pulsation(omega)

17
18 | # Acquisition de 1000 valeurs (1000*0.01 = 1s)
19 | mesures = banc.acquisition(1000)

20
21 | # Alignement du potentiomètre et conversions
22 | temps = mesures[:, 0] / 1000 | # en secondes
23 | max_pot = max(mesures[:, 2])
24 | moy_pot = (max_pot + min(mesures[:, 2])) / 2
25 | commande = mesures[:, 1]
26 | potentiometre = (mesures[:, 2] - moy_pot) / (
27 | max_pot - moy_pot) * 10 | # en degrées
28 | imu = -mesures[:, 5] * 180 / np.pi | # en degrées

29
30 | banc.close() | # Fermeture de la connexion

31
32 | return [temps , commande , potentiometre , imu]

33

34
35 | def gain(entree , sortie):
36 | amplitude_entree = max(entree) - min(entree)
37 | amplitude_sortie = max(sortie) - min(sortie)

38
39 | return 20 * np.log10(abs(amplitude_sortie / amplitude_entree))

40

41
42 | # Instance du banc d'essais
43 | banc = ComBanc(baudrate=115200, port='/dev/ttyUSB0')
44 | """ POUR FAIRE L'ACQUISITION D'UN POINT
45 | temps , commande , potentiometre , imu = acquisition(banc , 1.5)
46 | print(gain(potentiometre[5:], imu[5:]))

47
48 | plt.figure(figsize=(8, 4))
49 | plt.plot(temps[5:], potentiometre[5:], "+:", label="Potentiomètre")
50 | plt.plot(temps[5:], imu[5:], "+:", label="IMU")
51 | plt.xlabel("Temps (en secondes)")
52 | plt.grid(); plt.legend(); plt.show()
53 | """

54
55 | # Trace le diagramme de Bode
56 | bode_imu = Bode(title="Gain de Bode expérimental de la centrale inertielle")

57
58 bode_imu.omegas , bode_imu.gains = np.loadtxt("bode_imu.csv")

59
60 | # On affiche le résultat
61 | plt.figure(figsize=(8, 4))
62 | bode_imu.plot_gain()
63 | plt.tight_layout()
64 | plt.show()

### 2.3 Script pour le traitement du signal du pendule pesant

### 2.3.1 pendule.py

import numpy as np
import matplotlib.pyplot as plt from scipy import stats

def lireDonneesLatis(nom_fichier):
""" Charge le fichier Latis en une matrice de données """

donnees = np.loadtxt(nom_fichier , delimiter=';', skiprows=1)
10 | donnees[:, 1] *= 9 | # conversion tension en degree , facteur constructeur
| return donnees

def trouverCoupures(liste_grandeur , liste_temps):
""" Renvoie les temps où la grandeur passe du signe - à + """

liste_coupures = []
for i, t in enumerate(liste_temps[:-1]):
if liste_grandeur[i] < 0 and liste_grandeur[i + 1] > 0: liste_coupures.append([i, t])
return np.array(liste_coupures)

def tronquerDonnees(donnees , n_periodes):
""" Tronque le début des données et laisse n_periodes périodes """

liste_coupures = trouverCoupures(donnees[:, 1], donnees[:, 0]) debut = int(liste_coupures[0, 0])
if n_periodes:
fin = int(liste_coupures[n_periodes , 0])
else:
fin = -1
return donnees[debut:fin, :], liste_coupures[:n_periodes , :]

def plotAngle(titre , fichier , from_i , n_periodes , calcul_periodes=True):
""" Trace l'angle du pendule à partir du point from_i sur n_periodes périodes """

donnees_brut = lireDonneesLatis(fichier)

# Centre les points

donnees_brut[:, 1] += -np.average(donnees_brut[-10000:, 1])

# Tronque les données

donnees , liste_coupures = tronquerDonnees(donnees_brut[from_i:, :], n_periodes)
plt.xlim(donnees[0, 0], donnees[-1, 0])
m = max(donnees[:, 1]) + 1
plt.ylim(-m, m)

# Graduations et calcul de la période

if calcul_periodes:
plt.gca().set_xticks(np.round(liste_coupures[:, 1], 1))
O = []
for i in range(len(liste_coupures[:, 1]) - 1): O.append(liste_coupures[i + 1, 1] - liste_coupures[i, 1]) moyenne = np.average(O)
ecart_type = np.std(O)
periode = "Période = " + str(np.round(moyenne , 2)) + " +/- " + str( np.round(ecart_type , 2)) + " s"
style_text_pyplot = dict(
boxstyle='square', facecolor='white', alpha=0.8)
plt.text(

64 | donnees[-1, 0],
65 | m + 1,
66 | titre + " : " + periode ,
67 | bbox=style_text_pyplot ,
68 | fontsize=12,
69 | verticalalignment='top',
70 | horizontalalignment='right')

71
72 | # Graphique
73 | plt.xlabel("Temps (en seconde)")
74 | plt.ylabel("Angle du\npendule (degrés)")
75 | plt.plot(donnees[:, 0], donnees[:, 1], "k.", markersize=1.)
76 | plt.grid()

77

78
79 | for a in ["20", "30"]:
80 | plt.figure(figsize=(10, 3))
81 | plt.subplot(211)
82 | plotAngle("Sans la caméra", "s_" + a + ".csv", -6000, 20)
83 | plt.subplot(212)
84 | plotAngle("Avec la caméra", "a_" + a + ".csv", -6000, 20)
85 | plt.tight_layout()

86
87 plt.show()

## 3 Code MATLAB pour acquérir les rampes envoyées au servomoteur

### 3.1 Fonctions

### 3.1.1 reel_faireAcquisition.m : acquisition d’une rampe sur le servomoteur

1 | function [ commandes , reponses ] = reel_faireAcquisition( vitesse )
2 | % Permet d'effectuer l'acquisition d'une rampe de vitesse (en us/ms)

3
4 | sys = reel_SystemeReel(); | % Connexion au système réel
5 | sys.nouvelle_rampe(vitesse) | % Lance une rampe à la vitesse donnée en us/s
6 | waitfor(sys, 'faire_acquisition', false) | % Attend la fin de l'acquisition
7 | donnees_reel = sys.donnees; | % Récupère les données
8 | sys.close(); | % Ferme la connexion

9
10 | % Extrait les colonnes
11 | commandes = [donnees_reel(:,1)/1000, donnees_reel(:,2)];
12 | reponses = [donnees_reel(:,1)/1000, donnees_reel(:,3)];

13
14 end

### 3.1.2 reel_faireRegression.m : régression affine entre l’entrée et la sortie

1 | function [ coeff_regression , rcarre ] = reel_faireRegression( commande , reponse )
2 | % Donne les coefficients de la fonction affine
3 | % permettant de passer du retour du potentiomètre à la commande en us

4
5 | coeff_regression = polyfit(commande , reponse , 1); | % Regression

6
7 | % Calcul du coeff r au carré
8 | yfit = polyval(coeff_regression , commande);
9 | yresid = reponse - yfit;
10 | SStotal = (length(reponse)-1) * var(reponse);
11 | rcarre = 1 - sum(yresid.^2)/SStotal;

12
13 end

### 3.1.3 reel_rognerRampe.m : rogne le signal de 5s au début et à la fin

1 function [ temps_rognee , commande_rognee , reponse_rognee ] = reel_rognerRampe( temps , commande , reponse )
2 % Supprime les 5 premières et dernières secondes pour ne garder que la rampe

3
4 | reel_periode_echantillonage = 100; % ms
5 | t_rognage = 5000; % ms
6 | n = floor(t_rognage/reel_periode_echantillonage);

7
8 | temps_rognee = temps(n:end-n);
9 | commande_rognee = commande(n:end-n);
10 | reponse_rognee = reponse(n:end-n);

11
12 end

### 3.1.4 reel_traceCourbe.m : trace l’entrée et la sortie du servomoteur

1 | function reel_traceCourbe( entree , sortie )
2 | % Trace l'entrée et la sortie selon le temps.

3
4 | figure; hold all; grid on;
5 | plot(entree , 'LineWidth', 2);
6 | plot(sortie , 'LineWidth', 2);
7 | legend('Commande de position (us)', 'Position mesurée (us)')
8 | legend('Location', 'southeast')
9 | xlabel('t (en secondes)')

10
11 end

3.1.5 reel_traceRegression.m : trace la sortie en fonction de l’entrée du servomoteur (avec superposition de la régression)

1 | function reel_traceRegression( commande , reponse , coeff_regression , rcarre )
2 | % Trace le signal du potentiomètre (10 bits) en fonction de la commande en us
3 | % Ajoute par dessus la regression effectuée.

4
5 | figure;
6 | hold all;
7 | grid on;
8 | z = coeff_regression(1)*commande + coeff_regression(2);
9 | plot(commande , [reponse z], 'LineWidth', 2);
10 | legend('Signal expérimental', strcat('Réduction linéaire : r=', num2str(rcarre)),
'Location', 'southeast')
11 | xlabel('Commande')
12 | ylabel('Réponse réelle filtrée')

13
14 end

3.1.6 reel_SystemeReel.m : définit un objet représentant la communication avec le système réel

1 | classdef reel_SystemeReel < WebSocketClient
2 | % Abstraction de la communication avec le stabilisateur
3 | % Utilise la librarie MatlabWebSocket de Jérémy Béjanin (licence MIT)

4
5 | properties
6 | donnees | % Colonnes : temps , commande , potentiomètre
7 | faire_acquisition = false
8 | retour_commande_recu = false
9 | duree = 0
10 | nb_valeurs = 0
11 | i_valeur = 1
12 | end

13
14 | methods
15 | function obj = reel_SystemeReel()
16 | obj@WebSocketClient('ws://192.168.4.1:81'); | % Objet parent
17 | end

18
19 | function lance_acquisition(obj)
20 | % Prépare le tableau en mémoire et lance l'acquisition
21 | obj.donnees = zeros(obj.nb_valeurs , 3);
22 | obj.i_valeur = 1;
23 | obj.faire_acquisition = true;
24 | end

25
26 | function nouvelle_rampe(obj, vitesse)
27 | % Demande au système d'effectuer une rampe

28
29 | vitesse_puissance_10 = floor(log10(vitesse))-1;
30 | vitesse_deux_chiffres = vitesse * 10^(-vitesse_puissance_10);

31
32 | message = strcat('#', sprintf('%02X', vitesse_deux_chiffres), sprintf('%X',
vitesse_puissance_10+8));
33 | fprintf('Envoie la commande %s\n', message);
34 | obj.send(message);

35
36 | % Attend le retour de la commande
37 | waitfor(obj, 'retour_commande_recu', true);
38 | obj.retour_commande_recu = false;

39
40 | % Lance l'acquisition
41 | obj.lance_acquisition();
42 | end
43 | end

44
45 | methods (Access = protected)

46 | function onOpen(~, message)
47 | fprintf('%s\n',message); | % Message de connexion
48 | end

49
50 | function onTextMessage(obj, message)
51 | if obj.retour_commande_recu == false && message(1) == '#'
52 | % Si message commence par "#"
53 | % alors c'est un retour de commande donnant la durée
54 | fprintf('Retour : %s\n', message);
55 | len = length(message);
56 | obj.duree = str2double(message(2:len))+10000; % marge de 10s
57 | obj.nb_valeurs = uint32(obj.duree/100); % échantillon tous les 100ms
58 | obj.retour_commande_recu = true;
59 | elseif obj.faire_acquisition == true
60 | % Stocke les données si acquisition
61 | ligne = cellfun(@str2double , strsplit(message , ','));
62 | obj.donnees(obj.i_valeur , :) = ligne;

63
64 | % S'il y a eu assez d'acquisitions , alors on stoppe
65 | obj.i_valeur = obj.i_valeur + 1;
66 | if obj.i_valeur > obj.nb_valeurs
67 | fprintf('Fin acquisition\n');
68 | obj.faire_acquisition = false;
69 | end
70 | end
71 | end

72
73 | function onBinaryMessage(~, ~)
74 | % Ignorer
75 | end

76
77 | function onError(~, message)
78 | fprintf('Erreur : %s', message); | % Affiche l'erreur
79 | end

80
81 | function onClose(~, message)
82 | fprintf('%s\n', message); | % Message de déconnexion
83 | end
84 | end
85 | end

### 3.2 Scripts d’exemple

### 3.2.1 Effectue un grand nombre d’essais pour affiner la régression

1 | % Vitesse de la rampe en entrée (le plus faible possible)
2 | vitesse_rampe = 0.005; % us/ms
3 | n_mesures = 20;

4
5 | regressions = zeros(n_mesures , 3);
6 | i_mesure = 1;
7 | while i_mesure <= n_mesures
8 | fprintf('Lancement de la %deme mesure\n', i_mesure);

9
10 | % Effectue l'acquisition
11 | [reel_temps , reel_commande , reel_reponse] = reel_faireAcquisition(vitesse_rampe);

12
13 | % Filtrage de la réponse du potentiomètre
14 | reel_reponse = medfilt1(reel_reponse , 10);

15
16 | % Rogne pour ne garder que la rampe
17 | [reel_temps , reel_commande , reel_reponse] = reel_rognerRampe(reel_temps ,
| reel_commande , reel_reponse);

18
19 | % Effectue la regression
20 | [coeff_regression , rcarre] = reel_faireRegression(reel_commande , reel_reponse);

21
22 | if rcarre > 0.999
23 | % Stockage du résultat
24 | regressions(i_mesure ,:) = [coeff_regression , rcarre];

25
26 | % Affiche le résultat
27 | reel_traceRegression(reel_commande , reel_reponse , coeff_regression , rcarre);
28 | reel_traceCourbe(reel_temps , reel_commande , reel_reponse);

29
30 | % Incrémente
31 | i_mesure = i_mesure + 1;
32 | end
33 | end
| 3.2.2 Test de suivi d’une rampe
1 | % Vitesse de la rampe en entrée
2 | vitesse_rampe = 1.5; % us/ms

3
4 | % Effectue l'acquisition
5 | [reel_commande , reel_reponse] = reel_faireAcquisition(vitesse_rampe);

6
7 | % Applique la fonction trouvée par regression
8 | reel_reponse_r = reel_reponse./0.3-22.81/0.3;

9
10 | % Affiche le résultat
11 | reel_traceCourbe(reel_commande , reel_reponse_r);

## 4 Simulations MATLAB Simulink

### 4.1 Simulation du servomoteur

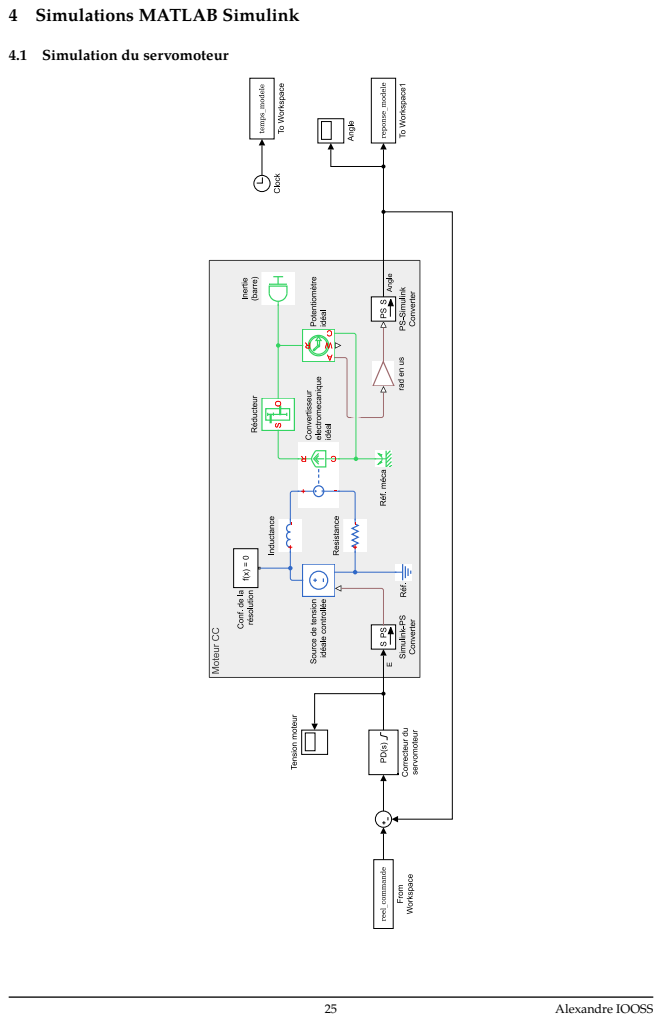
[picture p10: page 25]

### 4.2 Simulation complète du stabilisateur

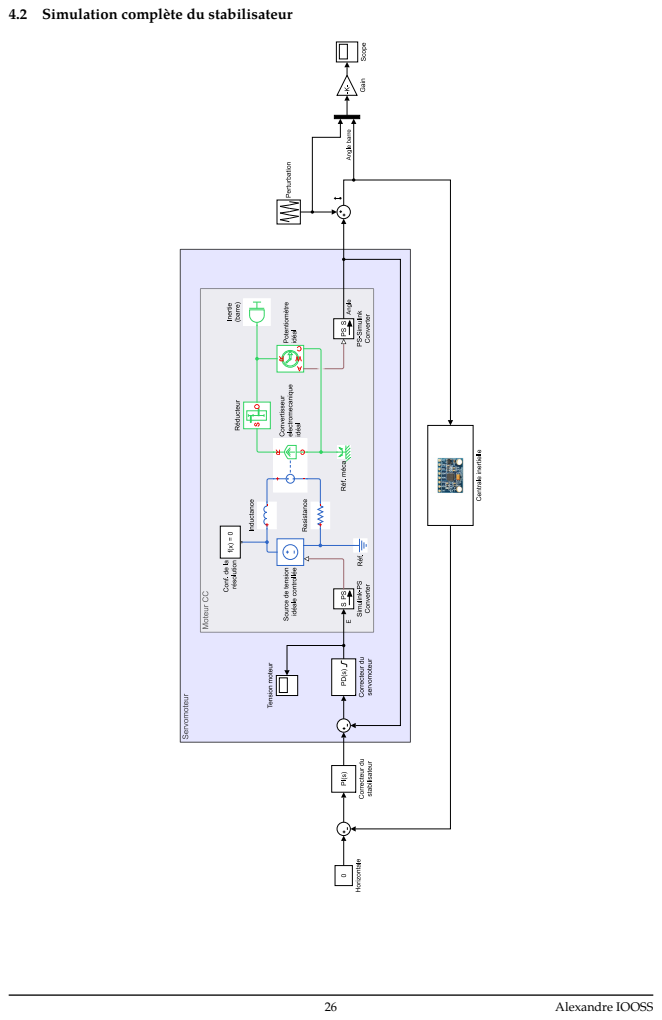
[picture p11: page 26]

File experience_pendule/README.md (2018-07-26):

# Expérience du pendule d'inertie

Le but du script [pendule.py](pendule.py) est de mesurer la période
d'oscillation d'un pendule Jeulin (données exportées en CSV).

## Intérêt

Avec la période du pendule, en appliquant le théorème du moment dynamique sur
son axe, on obtient une formule qui permet de retrouver l'inertie de ce que l'on
fait osciller.

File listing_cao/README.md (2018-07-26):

# Listing de la CAO

Le listing de la CAO que j'ai apporté le jour de l'oral est
[au format PDF ici](listing_cao.pdf).

## Compilation

J'utilise Pandoc pour générer ce listing LaTeX.

Il suffit de demander à Pandoc de convertir [listing_cao.md](listing_cao.md)
en PDF.

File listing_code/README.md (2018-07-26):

# Listing du code

Le listing du code que j'ai apporté le jour de l'oral est
[au format PDF ici](listing_code.pdf).

## Compilation

J'utilise Pandoc pour générer ce listing LaTeX.

Il suffit de demander à Pandoc de convertir [listing_code.md](listing_code.md)
en PDF.

Pour générer ce listing vous devez avoir les fichiers sources bien placés
relativement au Markdown.

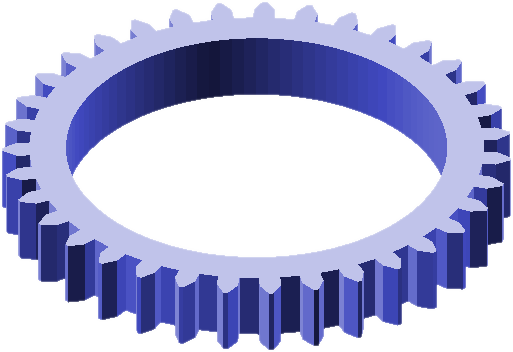
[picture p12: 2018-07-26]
listing_cao/cao/pignon_moteur.png

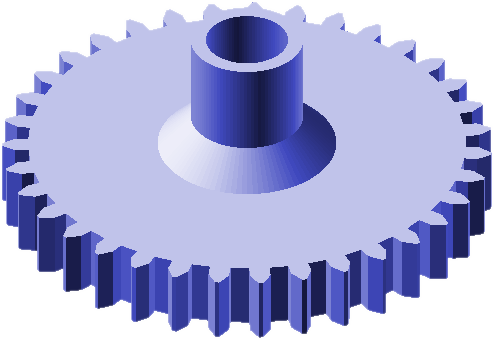
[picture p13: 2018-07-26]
listing_cao/cao/pignon_potentiometre.png

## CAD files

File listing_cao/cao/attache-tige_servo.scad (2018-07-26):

$fn=100;     // Nombre de facettes dans une révolution
gap = 0.05;  // Espace pour encastrer les pièces

/* Tige */
module tige() {
    longueur_tige = 330.8;  // Mesurée au pied à coulisse
    diametre_tige = 12 + gap;  // ISO + espace pour emboîter
    decalage_trou = 8.6;  // Mesuré au pied à coulisse

    color([0.5, 0.5, 0.5, 1]) rotate([0,90,0]) difference() {
        cylinder(h=longueur_tige, r=diametre_tige/2, center=true);  // Tige
        translate([0,6.8,0]) cube([20,2,30], center=true);  // Partie limée
        translate([0,0,-decalage_trou]) rotate([90,0,0])
            cylinder(h=20, r=1.5+gap, center=true);  // Perçage
    }
}

/* Attache servo-tige */
module attache_servo_tige() {
    distance_attache = 16;  // Distance entre les 2 trous sur l'attache servo
    epaisseur_attache = 3;  // Épaisseur de l'attache donnée par le constructeur
    diametre_tige = 12 + gap;  // ISO + espace pour emboîter
    decalage_trou = 8.6;  // Mesuré au pied à coulisse

    union() {
        // Partie épousant la forme de la tige
        difference() {
            rotate([0, 90, 0]) cylinder(h=30, r=8, center=true);
            tige();
            translate([-decalage_trou,0,0])
                rotate([90,0,0]) cylinder(h=20, r=1.5+gap*2, center=true);
            
            // Ajout suite au prototype : permet d'autoriser une déformation
            translate([0,-2,7]) cube([32,1,5], center=true);
        }
        
        // Partie d'accroche au moteur
        difference() {
            translate([0,8.2,0]) rotate([90,0,0])
                cylinder(r=13, h=epaisseur_attache, center=true);  // Forme de base
            translate([-decalage_trou,8,0]) rotate([90,0,0]) 
                cylinder(h=5, r=5.3/2+gap, center=true);  // Trou de la vis
            translate([0,8,distance_attache/2]) rotate([90,0,0]) 
                cylinder(h=5, r=1+gap, center=true);  // Trou en haut
            translate([0,8,-distance_attache/2]) rotate([90,0,0]) 
                cylinder(h=5, r=1+gap, center=true);  // Trou en bas
        }
        
        // Renforcements
        difference() {
            translate([-10,0,diametre_tige/2+gap]) cube([20,8,1.8]);
            translate([0,5,distance_attache/2]) rotate([90,0,0]) cylinder(h=10, r=1.5, center=true);
        }
        difference() {
            translate([-10,0,-1.9-diametre_tige/2-gap]) cube([20,8,1.8]);
            translate([0,5,-distance_attache/2]) rotate([90,0,0]) cylinder(h=10, r=1.5, center=true);
        }
    }
}

attache_servo_tige();

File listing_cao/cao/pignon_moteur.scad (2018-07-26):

// Bibliothèque Gear Generator écrite par Longrange, sous licence Creative Commons Attribution.
use <GearGeneratorV2.scad>;

r = 27.7/2;  // Rayon du moteur

difference() {
    linear_extrude(height=5, center=true, convexity=10)
            gear(number_of_teeth=35,diametral_pitch=1);
    cylinder(h=5*4, r=r, center=true, $fn=100);
}

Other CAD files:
listing_cao/cao/attache_potentiometre.scad
listing_cao/cao/pignon_potentiometre.scad
listing_cao/cao/GearGeneratorV2.scad

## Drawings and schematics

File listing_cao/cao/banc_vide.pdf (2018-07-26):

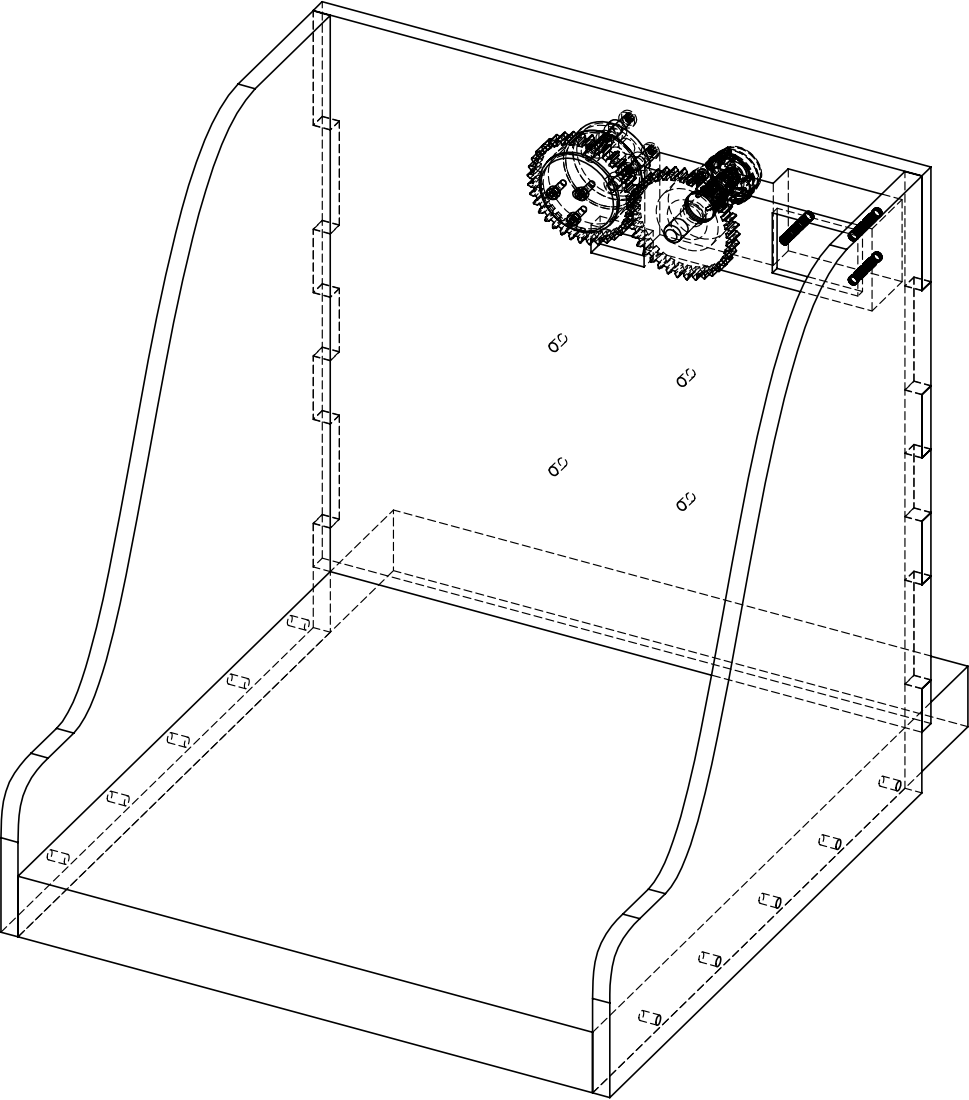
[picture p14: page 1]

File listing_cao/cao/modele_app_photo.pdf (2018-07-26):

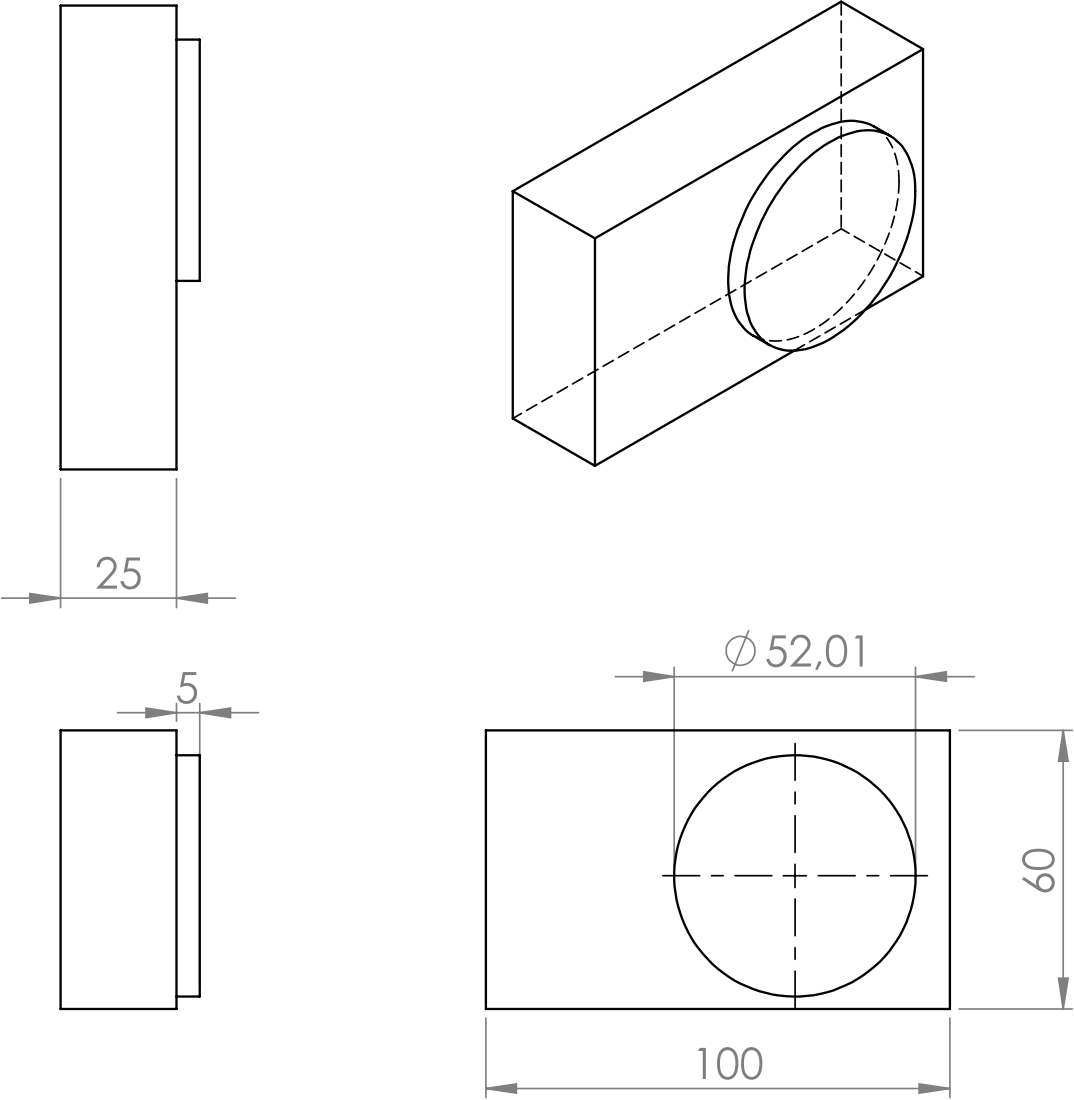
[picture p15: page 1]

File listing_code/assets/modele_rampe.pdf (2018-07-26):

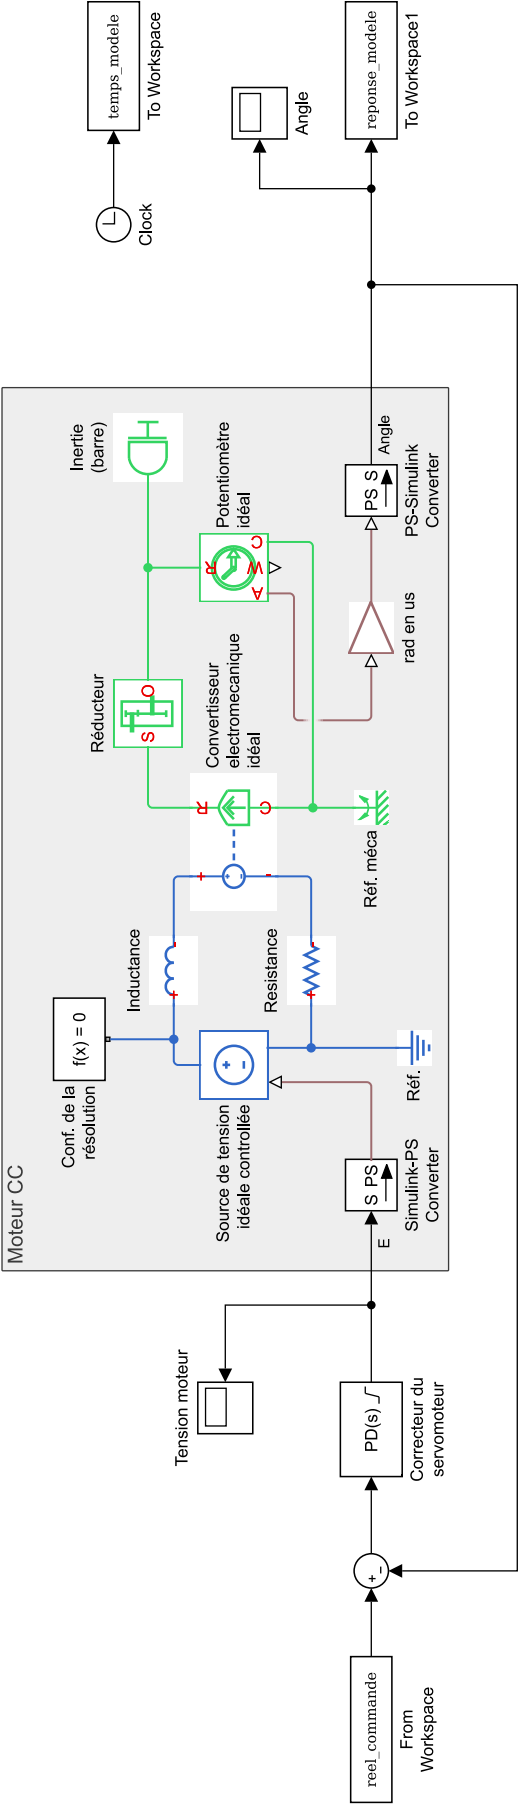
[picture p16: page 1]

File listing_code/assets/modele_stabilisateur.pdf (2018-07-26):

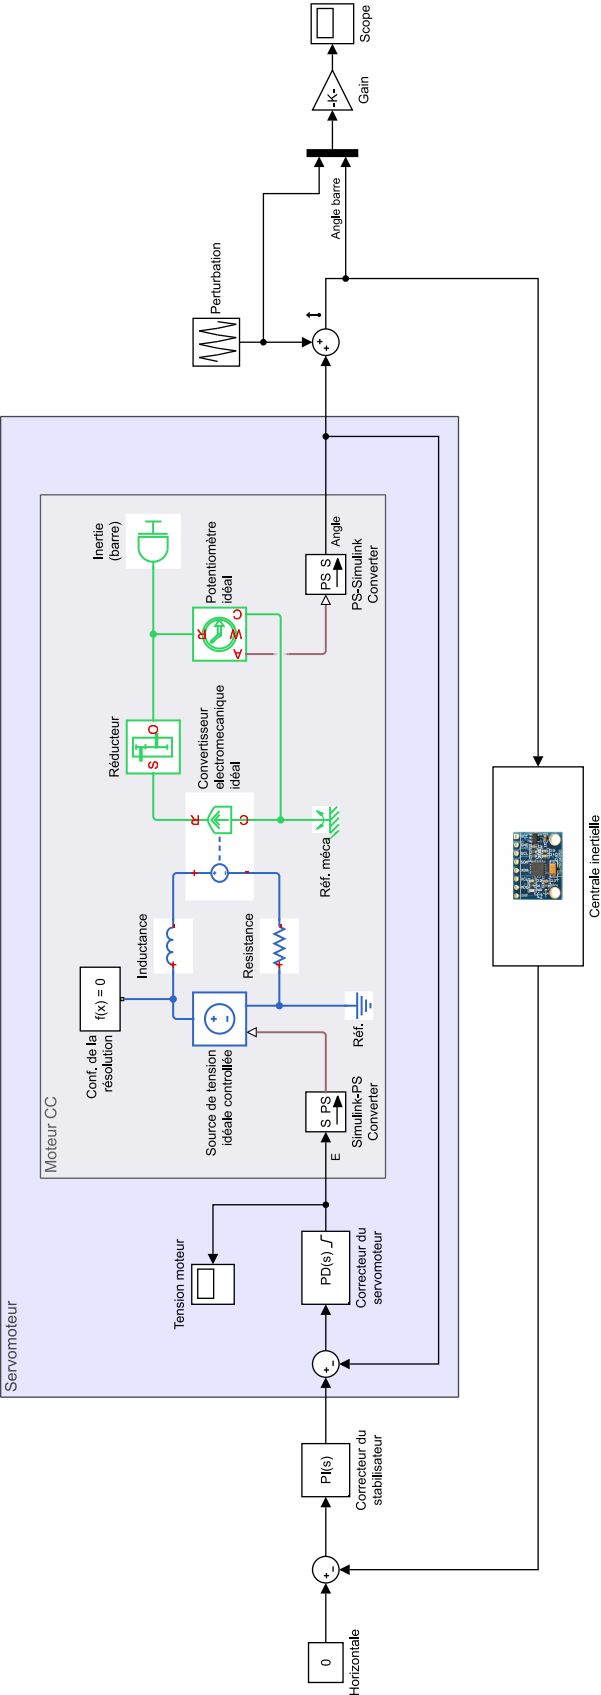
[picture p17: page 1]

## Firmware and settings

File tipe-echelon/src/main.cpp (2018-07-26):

/*
    This file is part of the TIPE step source code.

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
    You should have received a copy of the GNU General Public License
    along with this source code.  If not, see <https://www.gnu.org/licenses/>.
*/

#include "Arduino.h"
#include "ESP8266WiFi.h"
#include <Hash.h>
#include <Servo.h>
#include <SimpleTimer.h>
#include <WebSocketsServer.h>

// Timers
SimpleTimer timer_calcul_commande;
SimpleTimer timer_transmission_websocket;

// Objets
Servo servomoteur;
WebSocketsServer webSocket = WebSocketsServer(81);

// Variables pour la commande
unsigned long temps_commande = 0; // ms, temps à partir du début de la commande
unsigned long temps_commande_orig = 0; // ms, décalage temporel de l'origine
unsigned long temps_duree_rampe = 0;   // ms, durée de la rampe
int angle_servo = 950;                 // us, angle à envoyer au servomoteur
const int angle_servo_min = 950;       // us, angle minimal du servomoteur
const int angle_servo_max = 1800;      // us, angle maximal du servomoteur

// Initialisation du point d'accès Wifi
void initialiser_wifi() {
  WiFi.mode(WIFI_AP);                 // Point d'accès WiFi
  IPAddress ip_stab(192, 168, 4, 1);  // IP du stabilisateur & passerelle
  IPAddress masque(255, 255, 255, 0); // Masque de sous-réseau
  WiFi.softAPConfig(ip_stab, ip_stab, masque); // Serveur DHCP
  WiFi.softAP("Stabilisateur", "t1p3stabi");   // Nom et mot de passe du Wifi
}

// Commande en rampe
void commande_servomoteur() {
  if (temps_duree_rampe == 0) {
    // Aucune donnée n'a été reçue donc retour à l'origine
    angle_servo = angle_servo_min;
  } else {
    temps_commande = millis() - temps_commande_orig;

    if (temps_commande > 5000 and temps_commande < temps_duree_rampe + 5000) {
      // Effectue la rampe
      angle_servo = (temps_commande - 5000) *
                        (angle_servo_max - angle_servo_min) /
                        temps_duree_rampe +
                    angle_servo_min;
    } else if (temps_commande > temps_duree_rampe + 10000) {
      // La rampe est terminéee
      temps_duree_rampe = 0;
    }
  }

  servomoteur.writeMicroseconds(angle_servo);
}

// Transmet une mesure vers le socket réseau
void transmission_websocket() {
  int pot = analogRead(A0);
  String texte =
      String(temps_commande) + "," + String(angle_servo) + "," + String(pot);
  webSocket.broadcastTXT(texte);
}

// Gère la réception d'une commande (inspiré d'un exemple de WebSocket)
void rx_websocket(uint8_t num, WStype_t type, uint8_t *payload, size_t length) {
  if (type == WStype_TEXT and payload[0] == '#') {
    // Parsing de la commande (de la forme #FFF)
    uint32_t recu = (uint32_t)strtol((const char *)&payload[1], NULL, 16);
    int num_vitesse = ((recu >> 4) & 0xFF);      // 2 premiers chiffres
    int exp_vitesse = ((recu >> 0) & 0xF) - 0x8; // Puissance de 10

    // Calcul de la vitesse et de la durée de la rampe
    float vitesse = num_vitesse * pow(10, exp_vitesse);                // us/ms
    temps_duree_rampe = (angle_servo_max - angle_servo_min) / vitesse; // ms

    // Déplacement de l'origine temporel
    temps_commande_orig = millis();

    // Renvoie de la durée pour vérification
    webSocket.broadcastTXT("#" + String(temps_duree_rampe));
  }
}

// Initialisation
void setup() {
  servomoteur.attach(D6);          // Commande du servomoteur
  pinMode(A0, INPUT);              // Entrée du potentiomètre du servomoteur
  initialiser_wifi();              // Point d'accès Wifi
  webSocket.begin();               // Initialisation du Websocket
  webSocket.onEvent(rx_websocket); // Réception d'une commande

  timer_calcul_commande.setInterval(25, commande_servomoteur);
  timer_transmission_websocket.setInterval(75, transmission_websocket);
}

// Boucle principale qui lance les sous-boucles
void loop() {
  timer_calcul_commande.run();
  timer_transmission_websocket.run();
  webSocket.loop();
}

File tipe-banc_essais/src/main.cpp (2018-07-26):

/*
    This file is part of the TIPE test bench source code.

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
    You should have received a copy of the GNU General Public License
    along with this source code.  If not, see <https://www.gnu.org/licenses/>.
*/

#include "Arduino.h"
#include "BrushlessServo.h"
#include "SinArray.h"
#include "centrale_inertielle.h"

// Objets
BrushlessServo moteur;
SinArray sinArray;

// Variables pour la commande
int amplitude = 10; // en degrés
float pulsation = 0.;
float angle_moteur = 0.;       // en degrés
unsigned long temps_debut = 0; // origine temporelle

unsigned long temps_precedent_commande_moteur_boucle = 0;
unsigned long temps_precedent_transmission_serie_boucle = 0;
unsigned long temps_actuel = 0; // en ms

// Commande du moteur
void commande_moteur() {
  // Toutes les 10ms
  if (temps_actuel - temps_precedent_commande_moteur_boucle >= 10) {
    temps_precedent_commande_moteur_boucle = temps_actuel;

    // Commande du moteur
    if (pulsation > 0.1) {
      angle_moteur =
          amplitude * sinArray.getSin(pulsation * temps_actuel / 1000.);
      moteur.write(-angle_moteur - 20);
    }
  }
}

// Gère la réception d'une commande
void reception_serie() {
  if (Serial.available() > 0) {      // Si on a reçu quelque chose
    pulsation = Serial.parseFloat(); // Reception d'une nouvelle pulsation

    // Nouvelle origine des temps
    temps_debut = millis();
    temps_precedent_commande_moteur_boucle = 0;
    temps_precedent_transmission_serie_boucle = 0;
  }
}

// Transmet une mesure sur le port série
void transmission_serie() {
  // Toutes les 10 ms
  if (temps_actuel - temps_precedent_transmission_serie_boucle >= 10) {
    temps_precedent_transmission_serie_boucle = temps_actuel;

    Serial.print(millis() - temps_debut);
    Serial.print(",");
    Serial.print(String(angle_moteur, 4));
    Serial.print(",");
    Serial.print(analogRead(A0));
    Serial.print(",");
    Serial.print(String(centrale_inertielle_angles[0], 4));
    Serial.print(",");
    Serial.print(String(centrale_inertielle_angles[1], 4));
    Serial.print(",");
    Serial.println(String(centrale_inertielle_angles[2], 4));
  }
}

// Initialisation
void setup() {
  // Fast PWM Mode, diviseur de 1 : 16MHz/256
  // Extrait de https://www.arduino.cc/en/Tutorial/SecretsOfArduinoPWM
  TCCR1B = (TCCR1B & 0b11111000) | 0x01;
  TCCR2B = (TCCR2B & 0b11111000) | 0x01;

  moteur.attach(9, 10, 11); // Définition du moteur Brushless
  // moteur.setOutputPower(160);  // Réduction de la tension

  Serial.begin(115200);              // Communication série
  pinMode(A0, INPUT);                // Entrée du potentiomètre
  sinArray.generate();               // Précalcul du table de valeurs de sinus
  initialiser_centrale_inertielle(); // Centrale inertielle
}

// Boucle principale du programme
void loop() {
  // On arrête le programme si la centrale ne fonctionne pas
  if (!centrale_inertielle_initialisee)
    return;

  temps_actuel = millis() - temps_debut;

  boucle_centrale_inertielle(); // Centrale inertielle
  commande_moteur();            // Commande du moteur
  transmission_serie();         // Transmission des mesures
  reception_serie();            // Réception d'une commande
}

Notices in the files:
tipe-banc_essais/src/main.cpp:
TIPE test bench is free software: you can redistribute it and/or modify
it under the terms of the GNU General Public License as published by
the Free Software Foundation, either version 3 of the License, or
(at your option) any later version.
